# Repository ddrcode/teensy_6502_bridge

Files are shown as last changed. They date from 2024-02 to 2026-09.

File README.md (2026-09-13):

# W65C02-Serial port bridge for Teensy 4.1

This project is a simple bridge between the [W65C02 CPU](https://westerndesigncenter.com/wdc/documentation/w65c02s.pdf)
and a serial port, implemented for the [Teensy 4.1](https://www.pjrc.com/store/teensy41.html) development board.

The main purpose of this project is to provide cycle-by-cycle debugging capabilities for the W65C02, but it can serve
other purposes too, e.g.:

- __Comparative debugging for emulators__:
  You can run your 6502-family emulator in parallel with an actual CPU and compare the results
  in order to measure the accuracy of your emulator.
- __Emulated 8-bit computers with a physical processor__:
  You can implement an emulator of an 8-bit, 6502-based computer (e.g. the C64) that works
  (via this bridge) with a real CPU, while the other components of the system (like RAM, ROM,
  or the video chip) remain emulated
  (something like the [Neo 6502](https://www.olimex.com/Products/Retro-Computers/Neo6502/open-source-hardware)).

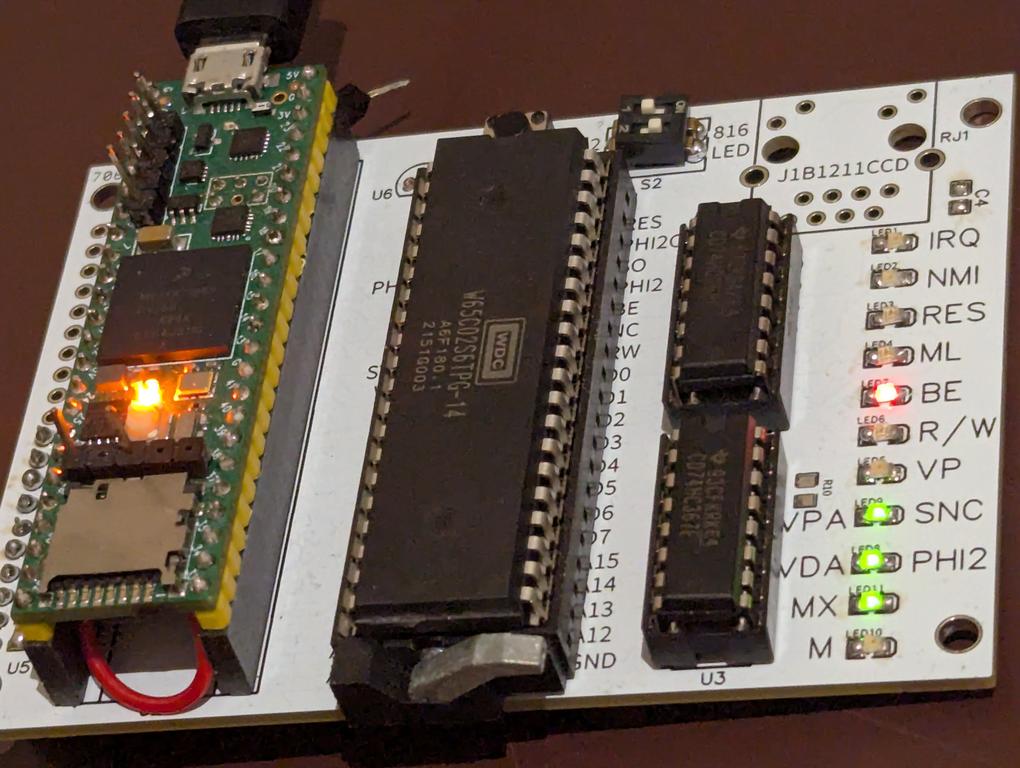
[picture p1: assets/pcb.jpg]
Example wiring


## Content of this repo

- C++ code for the Teensy 4.1 that enables full control over the W65C02 CPU via a serial port.
- An alternative [bare-metal Rust firmware](./firmware-rust/) with the same wire protocol
  (no Arduino toolchain required).
- [Examples](./examples/) (in C++ and Rust) demonstrating how to use the bridge from a program running on a
  computer.
- Host-side tooling plus unit/integration tests that exercise the serial protocol and pin-handling logic.
- An explanation of how to wire the Teensy to the W65C02 on a breadboard.
- Complete [PCB design and schematics](./pcb/) (with some extra features).
- [Documentation](./docs/): the [protocol specification](./docs/protocol.md), development guides for
  [C++](./docs/development-guide-cpp.md) and [Rust](./docs/development-guide-rust.md), a
  [macOS guide](./docs/macos.md), and the [project vision](./docs/vision.md) (the bridge and
  the machine - two modes of using the board).

## Wiring

The W65C02 CPU is a 40-pin chip with 37 signal pins (2 pins are for
power/ground and pin 35 is unused). As the Teensy board is equipped with more than 40 digital
input/output pins and allows for a serial connection via USB, it seems to be a perfect match for this
project. It is very simple to create this bridge on a breadboard.

Below is a pinout diagram of the W65C02 and the Teensy, as well
as the mapping between the CPU and Teensy pins.

```text
                                                        Teensy 4.1
                                                     +--------------+
                W65C02                           --- | GND      VIN | ---
            +------------+                   VP/ --- |  0       GND | ---
    VP/ <-- |  1      40 | <-- RES/              --- |  1      3.3V | ---
    RDY <-> |  2      39 | --> PHI2O       PHI1O --- |  2        23 | --- RES/
  PHI1O <-- |  3      38 | <-- SO/          IRQ/ --- |  3        22 | --- PHI2O
   IRQ/ --> |  4      37 | <-- PHI2          ML/ --- |  4        21 | --- RDY
    ML/ <-- |  5     @36 | <-- BE           NMI/ --- |  5        20 | --- SO/
   NMI/ --> |  6      35 | --- NC           SYNC --- |  6        19 | --- BE
   SYNC <-- |  7     *34 | --> RW/            A0 --- |  7        18 | --- M
    VDD --> |  8     *33 | <-> D0             A1 --- |  8        17 | --- RW/
     A0 <-- |  9*    *32 | <-> D1             A2 --- |  9        16 | --- D0
     A1 <-- | 10*    *31 | <-> D2                --- | 10        15 | --- D1
     A2 <-- | 11*    *30 | <-> D3             A3 --- | 11        14 | --- D2
     A3 <-- | 12*    *29 | <-> D4             A4 --- | 12        13 | --- PHI2
     A4 <-- | 13*    *28 | <-> D5            VDD --- | 3.3V     GND | --- GND
     A5 <-- | 14*    *27 | <-> D6             A5 --- | 24        41 | --- D3
     A6 <-- | 15*    *26 | <-> D7             A6 --- | 25        40 | --- D4
     A7 <-- | 16*    *25 | --> A15               --- | 26        39 | --- D5
     A8 <-- | 17*    *24 | --> A14               --- | 27        38 | --- D6
     A9 <-- | 18*    *23 | --> A13            A7 --- | 28        37 | --- D7
    A10 <-- | 19*    *22 | --> A12            A8 --- | 29        36 | --- A15
    A11 <-- | 20*     21 | --> GND            A9 --- | 30        35 | --- A14
            +------------+                   A10 --- | 31        34 | --- A13
                                             A11 --- | 32        33 | --- A12
    * - tri-state pin,                               +--------------+
    @ - async,
    / - active on low,
    M - routed to CPU pin 35 through the configuration switch (S2) on the PCB;
        unused with a W65C02, carries the E (emulation) status of a W65C816
```

### Default configuration

The table below (and the pinout above) illustrates the default configuration of the project.
To adjust the pin mapping, modify the `PINS_MAP` macro definition in the
[configuration file](./configuration.h).

The pin assignment is organized so that it leaves one SPI interface
available (pins 1, 10, 26 and 27), which can be used for an additional device (e.g. the [PCB](./pcb/)
gives the option to connect an ILI9341 screen). The firmware can drive that screen as an optional
live front panel (logic analyzer, address/data readouts, clock rate) - see the
[C++ development guide](./docs/development-guide-cpp.md#optional-ili9341-display).

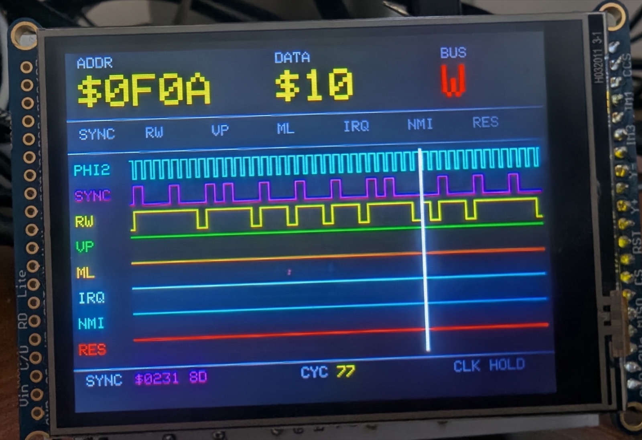
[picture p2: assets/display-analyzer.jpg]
Live front panel


| Teensy pin | CPU pin | CPU pin name | ←  → | CPU Pin name  | CPU pin | Teensy pin |
| --- | --- | --- | ---- | --- | --- | --- |
| 0 | 1 | Vector pull  | | Reset | 40 | 23 |
| 21 | 2 | Ready | | PHI2O | 39 | 22 |
| 2 | 3 | PHI1O | | Set overflow  | 38 | 20 |
| 3 | 4 | IRQ | | PHI2 | 37 | 13 |
| 4 | 5 | Memory lock  | | Bus enable | 36 | 19 |
| 5 | 6 | NMI | | NC / E (816)  | 35 | 18 (S2) |
| 6 | 7 | SYNC | | Read/Write | 34 | 17 |
| 3.3V | 8 | VDD | | D0 | 33 | 16 |
| 7 | 9 | A0 | | D1 | 32 | 15 |
| 8 | 10 | A1 | | D2 | 31 | 14 |
| 9 | 11 | A2 | | D3 | 30 | 41 |
| 11 | 12 | A3 | | D4 | 29 | 40 |
| 12 | 13 | A4 | | D5 | 28 | 39 |
| 24 | 14 | A5 | | D6 | 27 | 38 |
| 25 | 15 | A6 | | D7 | 26 | 37 |
| 28 | 16 | A7 | | A15 | 25 | 36 |
| 29 | 17 | A8 | | A14 | 24 | 35 |
| 30 | 18 | A9 | | A13 | 23 | 34 |
| 31 | 19 | A10 | | A12 | 22 | 33 |
| 32 | 20 | A11 | | Ground | 21 | GND |

### Minimal configuration

In the minimal configuration, the following CPU pins must be connected to the board:

- `A0-A15` - address bus (inputs)
- `D0-D7` - data bus (input or output)
- `RW` - read/write input; it indicates whether the data bus is in read (high) or write (low) state
- `PHI2` - clock signal input
- `GND` - ground, should be connected to a Teensy ground pin
- `VDD` - power; should be connected to the Teensy's 3.3V pin

In such a configuration the `RES`, `IRQ`, `NMI`, `BE` and `RDY` pins must also be connected to 3.3V,
ideally via a 1k resistor.

Please note that `RES` (pin 40) must be kept low for at least two cycles on power-on.
The bridge handles it programmatically, but if you intend not to connect the RES pin to the
Teensy, or want physical control over the reset state (e.g. in case of a power failure),
the best option is to drive the pin with a
[DS1818 Econo Reset](https://www.mouser.co.uk/datasheet/2/609/DS1818-3122611.pdf).

### Example

The photo shows the wiring on a solderable prototype board (a regular breadboard could be used instead).
All CPU pins are connected to the Teensy, apart from pin 35 (NC).
The CPU pin 8 (VDD) is connected via a [decoupling capacitor](https://en.wikipedia.org/wiki/Decoupling_capacitor).
Additionally, there are some LEDs indicating selected signals.

Example wiring

### Schematic and extended configuration

The schematic below illustrates the connectivity between the Teensy and the CPU, but also
provides some optional extras:

- a reset button
- indication LEDs
- SPI connectivity with an ILI9341 LCD.
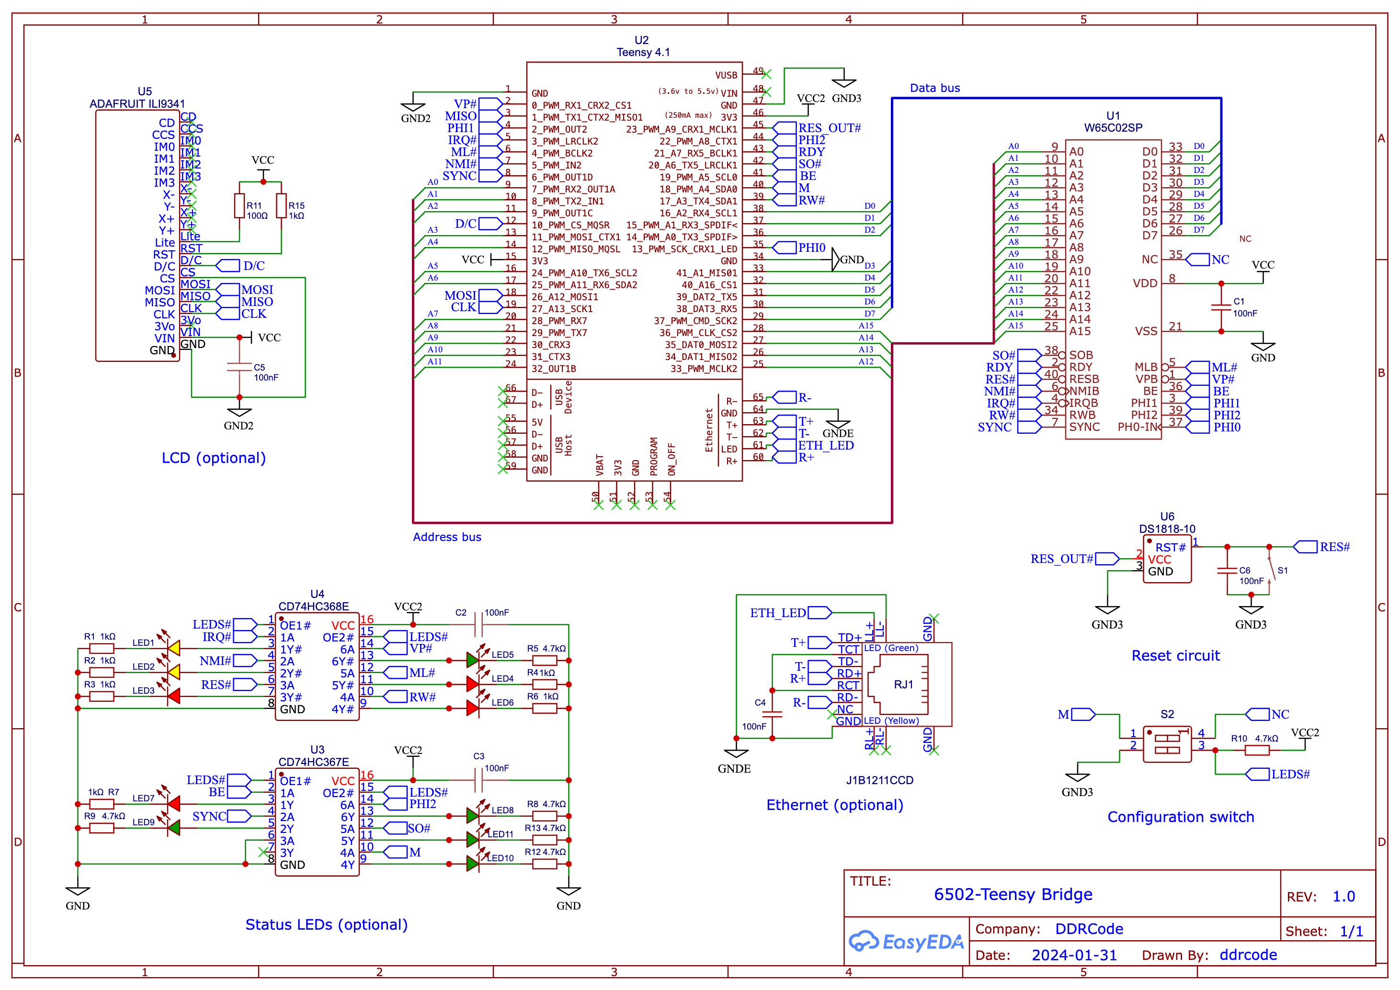
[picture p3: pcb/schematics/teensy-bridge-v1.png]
Schematic
  

### Warning

An incorrect connection may damage the CPU or the development board. Please pay extra attention to the
correctness of your wiring and double-check it before powering up your board.

## Compilation and execution

### With Arduino IDE and Teensyduino

1. Install the [Arduino IDE](https://www.arduino.cc/en/software)
1. Install and configure [Teensyduino](https://www.pjrc.com/teensy/teensyduino.html)
1. Clone this project into your Arduino sketches folder (usually `~/Arduino/sketches`)
1. Click menu `Sketch / Compile` to compile
1. Click menu `Sketch / Upload` to upload to the Teensy board

### With Arduino CLI

Follow [this
post](https://forum.pjrc.com/index.php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)
to see how to configure the Arduino CLI for Teensy, or do these steps (the third one is for Linux only):

```
arduino-cli config add board_manager.additional_urls https://www.pjrc.com/teensy/package_teensy_index.json
arduino-cli core install teensy:avr
wget https://www.pjrc.com/teensy/00-teensy.rules -P /etc/udev/rules.d
```

- to compile: `make build`
- to upload: `make upload`

`make upload` uses `teensy-loader-cli`, so the Teensy Loader application must be available on your PATH.

On macOS `make upload` may fail with `Device is in use by "dummy" driver`, and the serial
ports are named differently — see [Running the bridge on macOS](./docs/macos.md) for
working upload options and other Darwin-specific details.

### Running the host-side runners

After flashing the firmware you can exercise the bridge directly from your workstation. Both host examples
share the same CLI flags; at minimum you must provide the serial `--port` and the path to a 6502 binary via
`--program`. When you invoke the Makefile targets, the `PROGRAM` variable defaults to `examples/test.p`, and you
can point it somewhere else as needed.

The Makefile exposes convenience targets that forward those flags for you:

```bash
PORT=/dev/ttyACM0 make run-cpp   # builds and runs the C++ host runner
PORT=/dev/ttyACM0 make run-rust  # builds and runs the Rust host runner (cargo)
PROGRAM=examples/other.bin PORT=/dev/ttyACM0 make run-cpp
```

Pass `--halfcycles` to either executable if you want to log both halves of the clock and show the PHI pins in the
log output. Pass `--step` to execute cycle by cycle: the runner pauses after every cycle with the CPU frozen
(ideal for watching the indication LEDs) and advances on Enter - see the
[examples Readme](./examples/README.md) for the full list of step commands. Run `arduino-cli board list` whenever you need to confirm which `/dev/tty*` entry corresponds to the
Teensy (on macOS the port appears as `/dev/cu.usbmodem*` — see [docs/macos.md](./docs/macos.md)).

##### Install Arduino CLI and dependencies with Nix and Direnv

If you are not using Nix packages, then you don't know how much you are missing in terms of convenience and reproducible dev environments - [start](https://nixos.org/download) today :-)

1. Clone the repo and cd into the project's directory
1. If you use [Direnv](https://direnv.net/), just execute `direnv allow`; otherwise type `nix-shell`
1. Wait until all the dependencies download and configure
1. You can now use `make build` and `make upload`
1. I've added [`treefmt`](https://github.com/numtide/treefmt) to the dependencies, so you can format the
   code after changes by executing `treefmt`

## Example

There is a complete example program in the [examples folder](./examples) that demonstrates
how to execute a 6502 binary with the bridge and RAM emulated on the host machine
(not on the Teensy). See the [Readme file](./examples/README.md) for details.

## Data structure and message protocol

The host and the bridge exchange short, framed messages over the serial port: a type byte, a
payload and a checksum. In normal operation both sides exchange 7-byte _pins messages_ carrying
the state of all 40 CPU pins (one per bit) - one request-response pair per clock half-cycle, with
the host driving `PHI2` and emulating the memory. The bridge validates every incoming message and
responds with a short error message when it rejects one.

The complete specification - the message framing, the exact bit layout of the pins payload, the
messaging order and the timing characteristics - lives in [docs/protocol.md](./docs/protocol.md).

## Working with other CPUs from the 6502 family

This project is meant to work specifically with the W65C02 CPU. The main reason
is that the W65C02 is static, which means it can easily be cycled step by step at any speed -
very useful for debugging. Some other CPUs, like the C64's MOS6510, have
a minimum clock speed limitation (~100 kHz).

The project should work fine with other CPUs from the WDC family, especially with the
65C802, due to pin layout compatibility. Although untested, the 65C802 should work
as-is, without any changes to the current code.

There is a plan to make the project fully compatible with the W65C816, however that
requires some changes in the handling of the 24-bit address bus (there is already a
[ticket](https://github.com/ddrcode/teensy_6502_bridge/issues/3) for that).

This bridge may still work with some other CPUs from the 6502 family, but some adjustments
may be required, as those processors may have different pin layouts. Also,
a minimum clock speed requirement may be a blocker, due to the limited speed of the bridge itself
(see the section below). And finally - the WDC family processors work perfectly at 3V, which matches
the Teensy 4.1 pin voltage. Other processors, like the original 6502/6510, may be 5V-only.
That would require further modifications.

## Speed limitations

The speed of the bridge is limited by the speed of the serial port. The bridge sends 40 bits of data
in both directions for every single half-cycle (clock phase). To obtain a CPU speed of
1 MHz, the serial port would have to operate at 160 Mbit/s. Although the Teensy 4.1 is equipped
with a high-speed USB 2.0 port, which - in theory - allows for 480 Mbit/s, in reality the serial port
emulation uses a single USB channel only and there is an overhead related
to the creation of USB packets. The current speed I've achieved in my tests is around
0.5 Mbit/s. This is quite sufficient for any form of debugging and execution of test programs,
but definitely too slow for running any real-time applications.
For example, starting the C64 Kernal via the bridge takes around 300 seconds.

I've created a [ticket](https://github.com/ddrcode/teensy_6502_bridge/issues/8) for this issue.
Contributors are welcome!

## References

- [W65C02 datasheet](https://westerndesigncenter.com/wdc/documentation/w65c02s.pdf)
- [Teensy 4.1](https://www.pjrc.com/store/teensy41.html)
- [6502 Primer: What do I do with the "mystery" pins](https://wilsonminesco.com/6502primer/MysteryPins.html)

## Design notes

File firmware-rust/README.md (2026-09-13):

# W65C02-Teensy Bridge - Rust firmware

A bare-metal Rust implementation of the bridge firmware, functionally equivalent
to the C++ firmware in the repository root: the same
[serial protocol](../docs/protocol.md) (framed messages, checksum validation,
error replies), the same data-bus gating (driven only during the high clock
phase of read cycles), and the same high-speed USB. The host runners and test
programs work with either firmware unchanged.

Built on [teensy4-rs](https://github.com/mciantyre/teensy4-rs) (`teensy4-bsp`),
with USB CDC via `imxrt-usbd` + `usbd-serial`. No Arduino, no arduino-cli.

## Extras over the C++ firmware

- **Self-rebooting flash**: opening the serial port at **134 baud** reboots the
  board into the HalfKay bootloader (the same convention Teensyduino uses), so
  reflashing needs no button press:

  ```bash
  stty -f /dev/cu.usbmodemXXXX 134    # macOS (use /bin/stty if GNU coreutils shadows it)
  stty -F /dev/ttyACM0 134            # Linux
  ```

- The device enumerates as `W65C02 Bridge (Rust)` (serial `6502-RS-2`), so it is
  easy to tell which firmware is flashed.

## Building and flashing

```bash
cd firmware-rust
make build    # cargo build --release (rustup installs the target automatically)
make hex      # ELF -> teensy-6502-bridge.hex (llvm-objcopy from the toolchain)
make flash    # flash with teensy-loader-cli (see below)
make test     # host-side unit tests of the protocol/payload logic
```

`make flash` expects a native `teensy-loader-cli` on the PATH (on macOS build it
from source - see [docs/macos.md](../docs/macos.md); the nixpkgs build does not
work there). If the Rust firmware is already running, trigger the 134-baud
reboot first (or let `teensy-loader-cli -w` wait and press the button).

## Source layout

| File | Responsibility |
| ---- | --- |
| `src/main.rs` | Board/GPIO/USB setup and the request-response loop |
| `src/protocol.rs` | Message framing: sizes, checksums, error replies, byte-stream accumulator (host-tested) |
| `src/payload.rs`  | The 40-bit pin payload bit layout (host-tested, incl. a real hardware-captured vector) |
| `src/lib.rs` | `no_std` on target, `std` for host tests |

## Hardware notes (learned the hard way)

- Pin mapping comes from the `teensy4-pins` pad table - every pin is created
  through the HAL's type-checked API, so a wrong pin/port pairing fails at
  build/boot rather than silently writing to the wrong register.
- All output pads are configured with **SION** (Software Input On), so the
  driven levels can be read back through PSR. Without it, `handle_cycle`'s
  `RW && PHI2` bus gate reads PHI2 as always-low and the data bus is never
  driven - the CPU then executes garbage from a floating bus.
- Data-bus direction is flipped by re-running the HAL's documented-reentrant
  `Output::without_pin`/`Input::without_pin` constructors (a single GDIR
  register write per line).

## Limitations vs the C++ firmware

- No debug/diagnostics modes and no ILI9341 display support (the display could
  be added later with `embedded-graphics` + an `ili9341` driver crate).
- Async (embassy) is not used: `embassy-imxrt` targets the i.MX RT600 family,
  not the Teensy's RT1062. A polling loop is the right shape for this
  latency-bound protocol anyway; RTIC would be the natural framework if
  interrupt-driven structure is ever needed.

## Verification

The firmware passes the same hardware test battery as the C++ one: protocol
probe (checksum/type error replies, valid pins exchange), deterministic
cycle-exact soak runs, and the `examples/test.p` correctness check - at the
same throughput (~5,000 CPU cycles/s over high-speed USB).

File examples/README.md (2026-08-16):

# Example - program runner

This folder hosts the workstation-side programs (C++ and Rust) that toggle `PHI2`, emulate RAM, and exchange
pin states with the Teensy bridge over USB. Both implementations behave identically; choose the toolchain you
prefer.

## Requirements

- Teensy 4.1 running the bridge firmware from this repository
- A W65C02 wired to the Teensy (at minimum: address bus, data bus, `PHI2`, and `RW/`)
- A serial port path such as `/dev/ttyACM0`
- A 6502 binary (the demo uses `examples/test.p`)

## Quick start

Use the Makefile helpers to build and run either example with one command:

```bash
PORT=/dev/ttyACM0 make run-cpp
PORT=/dev/ttyACM0 make run-rust
PROGRAM=examples/custom.bin PORT=/dev/ttyACM0 make run-cpp
```

`PORT` selects the serial device while `PROGRAM` decides which binary is loaded into the emulated RAM. Append
`--halfcycles` to either command when you want to observe both halves of every cycle and include the `PHI1O/PHI2O`
signals in the log.

Append `--step` to execute the program cycle by cycle: the runner pauses after every logged cycle
(with the CPU frozen and its pins holding the printed state - ideal for watching the indication
LEDs), and waits for a command: `Enter` advances one cycle, a number runs that many cycles,
`c` switches back to free-running and `q` quits. Combined with `--halfcycles` it steps through
individual half-cycles.

## Manual compilation

If you prefer to compile by hand, follow the steps below.

### C++ version

1. Discover the Teensy port: `arduino-cli board list`
2. Build: `g++ -std=c++17 -O2 -o example.out *.cpp`
3. Run: `./example.out --port /dev/ttyACM0 --program ../test.p [--halfcycles]`

### Rust version

1. Discover the Teensy port: `arduino-cli board list`
2. Build: `cargo build`
3. Run: `cargo run -- --port /dev/ttyACM0 --program ../test.p [--halfcycles]`

## Expected result

If everything is connected correctly, the program should produce
output like the one shown below. It executes a tiny program that adds two
16-bit numbers together (see the [source](./test.asm)). Each line contains
all the relevant fields, so you can scroll freely without losing the column headers.

```text
Cycle=000009 Half=H Addr=$FFFC Data=$00 RW=R SYNC=0 VP=0 IRQ=1 NMI=1 RES=1
Cycle=000010 Half=H Addr=$FFFD Data=$02 RW=R SYNC=0 VP=0 IRQ=1 NMI=1 RES=1
Cycle=000011 Half=H Addr=$0200 Data=$A9 RW=R SYNC=1 VP=1 IRQ=1 NMI=1 RES=1
Cycle=000012 Half=H Addr=$0201 Data=$03 RW=R SYNC=0 VP=1 IRQ=1 NMI=1 RES=1
Cycle=000013 Half=H Addr=$0202 Data=$8D RW=R SYNC=1 VP=1 IRQ=1 NMI=1 RES=1
Cycle=000014 Half=H Addr=$0203 Data=$FF RW=R SYNC=0 VP=1 IRQ=1 NMI=1 RES=1
Cycle=000015 Half=H Addr=$0204 Data=$FF RW=R SYNC=0 VP=1 IRQ=1 NMI=1 RES=1
Cycle=000016 Half=H Addr=$FFFF Data=$03 RW=W SYNC=0 VP=1 IRQ=1 NMI=1 RES=1
```

The first few logged cycles may differ from run to run - they show the CPU's internal reset
sequence (dummy fetches and three stack accesses) before the reset vector is fetched from
`$FFFC`/`$FFFD`, with the vector pull clearly visible as `VP=0`. From that point on the trace
is fully deterministic.

Running the tools with `--halfcycles` prints both halves of every cycle and appends
`PHI1O`/`PHI2O` at the end of each line for deeper timing inspection.

## How does the example work?

1. The runner loads the binary at $0200, seeds the reset/IRQ/NMI vectors, and asserts reset low for two full cycles.
2. Each half-cycle writes a 40-bit pin snapshot to the bridge, toggling `PHI2` in the payload. The low phase captures
	the address and `RW/` state; the high phase either supplies memory data (reads) or stores results (writes).
3. Every completed bus operation is logged as labeled key/value pairs, so you can follow execution without a logic
	analyzer.

For more details see the development guides for [C++](../docs/development-guide-cpp.md) and
[Rust](../docs/development-guide-rust.md), and the [protocol specification](../docs/protocol.md).

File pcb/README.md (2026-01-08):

# PCB

This folder contains everything you need to fab the optional Teensy↔W65C02 carrier board: schematics, rendered
views, manufacturing files, and a bill of materials.

## Folder contents

- `schematics/` – source diagram plus a printable PNG
- `gerber/` – ready-to-send fabrication outputs (ZIP all files and upload to your PCB house)
- `assets/` – 3D/top/bottom previews for quick reference

## Schematics

schematics

## PCB Design

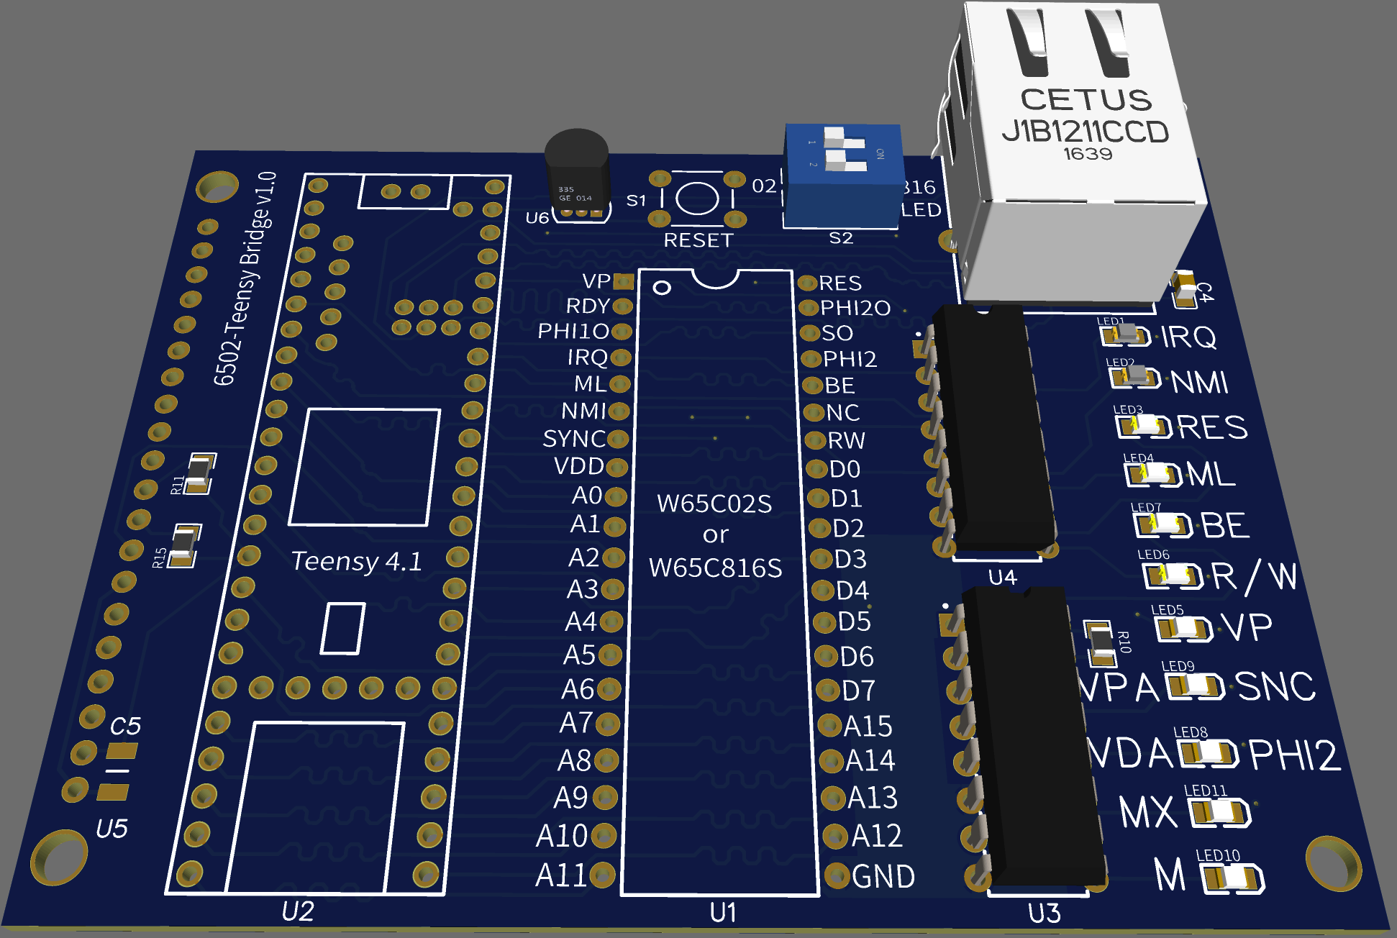
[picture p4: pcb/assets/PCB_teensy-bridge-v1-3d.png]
3d view


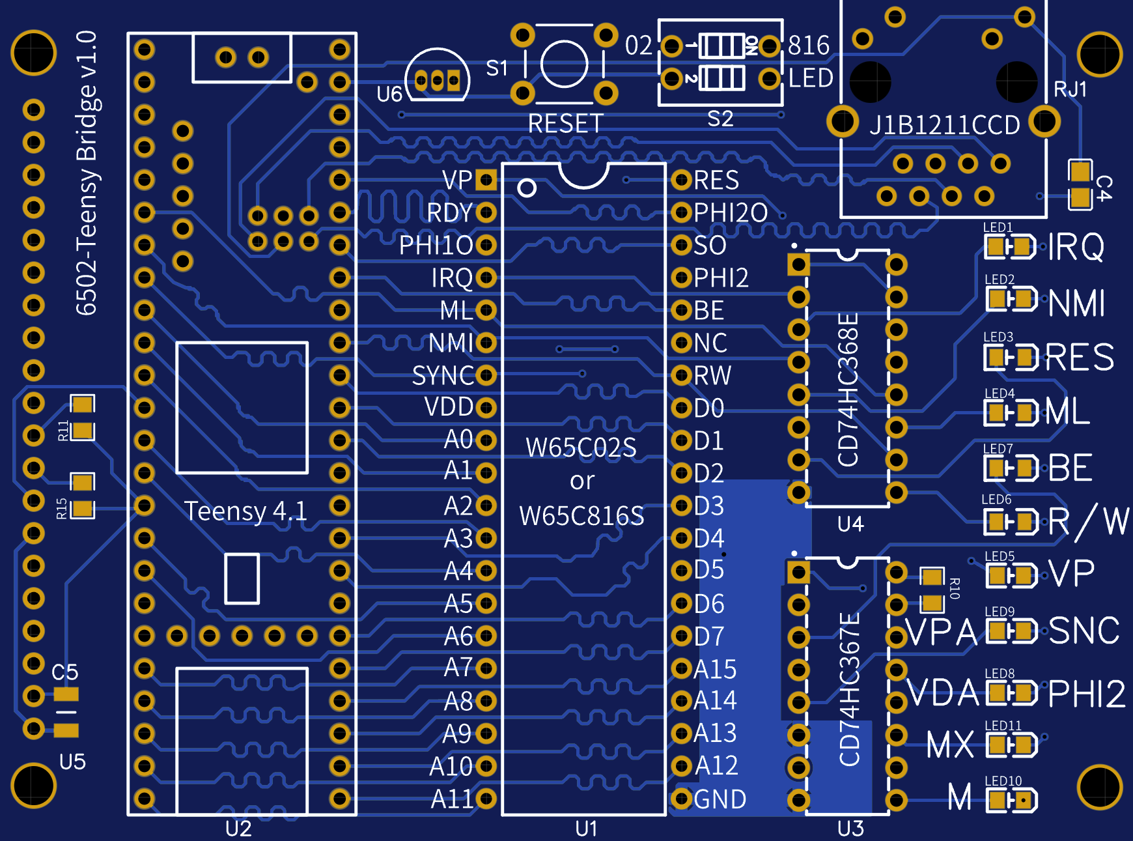
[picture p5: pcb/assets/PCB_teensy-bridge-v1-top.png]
Top view


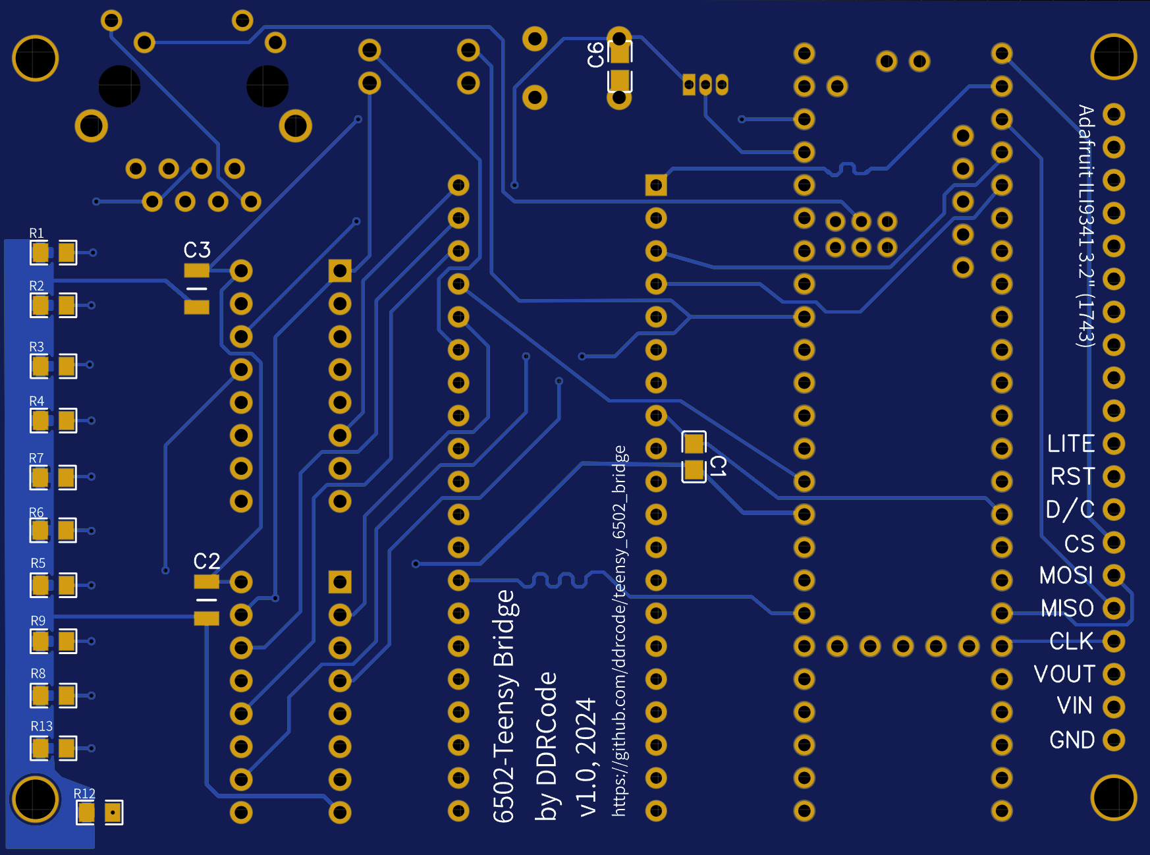
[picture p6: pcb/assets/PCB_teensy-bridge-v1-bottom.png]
Bottom view


## BOM

Populate only the components you care about: the mandatory list yields a minimal functional bridge, while the
optional sections add Ethernet, LED diagnostics, or an SPI display header.

### Mandatory components

| Ref | Component | Qty | Size | Description |
| --- | --- | --- | --- | --- |
| U1  | W65C02 or W65C816 | 1 | PDIP-40  | CPU |
| U2  | Teensy 4.1 | 1 | | Microcontroller dev board |
| U6  | [DS1818-10](https://www.mouser.co.uk/datasheet/2/609/DS1818-3122611.pdf) | 1 | TO-92-3  | EconoReset with push button |
| C1  | 100nF | 1 | 0805 SMD | Unpolarized capacitor |
| S1  | TL1105 | 1 | 4 pin | Tactile switch |
| S2  | ADE | 1 | DIP-2 | 2-pos DIP switch |

### Optional components

#### Ethernet

| Ref | Component  | Qty | Size | Description |
| --- | --- | --- | --- | --- |
| RJ1 | J1B1211CCD | 1 | | RJ45 Socket |
| C4  | 100nF | 1 | 0805 SMD | Unpolarized capacitor |

#### Debugging LEDs

| Ref | Component | Qty | Size | Description |
| --- | --- | --- | --- | --- |
| U3 | [CD74HC367E](https://www.ti.com/lit/ds/symlink/cd54hc368.pdf?ts=1706075936400) | 1 | PDIP-16  | Line driver |
| U4 | [CD74HC368E](https://www.ti.com/lit/ds/symlink/cd54hc368.pdf?ts=1706075936400) | 1 | PDIP-16  | Inverting line driver |
| C2,C3 | 100nF | 2 | 0805 SMD | Unpolarized capacitor |
| LED5, LED8-11  | Standard LED - SMD | 5 | 0805 SMD | Green LEDs |
| R5, R8-R11 | 4.7k Ohm | 5 | 0805 SMD | Resistors for green LEDs  |
| LED3-4, LED6-7 | Standard LED - SMD | 4 | 0805 SMD | Red LEDs |
| R3-R4, R6-R7 | 3k Ohm | 4 | 0805 SMD | Resistors for red LEDs |
| LED1, LED2 | Standard LED - SMD | 2 | 0805 SMD | Yellow LEDs |
| R1, R2 | 4.7k Ohm | 2 | 0805 SMD | Resistors for yellow LEDs |

#### SPI Screen

| Ref | Component | Qty | Size | Description |
| --- | --- | --- | --- | --- |
| U5  | [ADAFRUIT ILI9341](https://www.adafruit.com/product/1743) | 1 | PDIP-16  | 3.2", 320x200px SPI screen |
| C5  | 100nF | 1 | 0805 SMD | Unpolarized capacitor |
| R11 | 100 Ohm | 1 | 0805 SMD | Screen light resistor |
| R15 | 1k Ohm | 1 | 0805 SMD | Screen reset resistor |

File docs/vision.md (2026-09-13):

# Vision: one board, two modes

This project began as - and its name still says - a *bridge*: a Teensy 4.1 that hands full
control of a physical W65C02 to software running on a host computer. That mode is mature,
tested and in daily use. But the board that grew around the bridge - a 600 MHz
microcontroller, a real CPU, a screen, an Ethernet jack - turned out to be provisioned for
something more. This document names the two ways the board can be used, shows that they are
one architecture rather than two projects, and sketches where that leads.

## Mode 1 - the bridge (what exists)

```
 host machine  ── USB serial ──>  Teensy  ── 40 pins ──>  W65C02
 emulated world                   transparent             real CPU
 + the clock                      servant
```

The host owns everything: it drives the clock one half-cycle per message, emulates the
memory and peripherals, and sees the state of all 40 CPU pins in every reply (see the
[protocol specification](./protocol.md)). The CPU runs at a few kHz - limited by USB
round-trip latency - which is not a flaw but the point: every cycle is observable,
steppable and bit-for-bit reproducible.

This is the project's laboratory identity: cycle-by-cycle debugging, lockstep validation of
cycle-accurate emulators, and silicon-in-the-loop test suites. Everything in this repository
serves Mode 1 today.

## Mode 2 - the machine (what could exist)

```
                Teensy  ── 40 pins ──>  W65C02
                emulated world           real CPU
                + the clock
                + screen, keyboard,
                  storage, network
```

No serial connection and no host: the Teensy *is* the computer. It free-runs the clock,
serves the address space from its own RAM, maps ROM images from flash, and emulates the
peripherals - with the real 6502 as the one component that isn't emulated. The concept is
proven by the [Neo6502](https://www.olimex.com/Products/Retro-Computers/Neo6502/open-source-hardware) -
which the main README has cited as an inspiration since 2023. Mode 2 was always purpose #2
in the README; it just never had firmware.

The board is better prepared for this than its name suggests:

| Resource | Mode 2 role |
| --- | --- |
| 600 MHz Cortex-M7 | ~600 microcontroller cycles per CPU cycle at a 1 MHz bus - room for memory *and* device emulation; 1-3 MHz looks feasible bit-banged (the RP2040-based Neo6502 reaches ~6 MHz with PIO assist) |
| 512 KB tightly-coupled RAM | The entire 64 KB address space with single-cycle access, several times over |
| 8 MB flash | ROM images (a C64 kernal is 8 KB; this fits a thousand of them) |
| PSRAM pads (up to 16 MB) | RAM expansions - an emulated REU, banked memory for the '816 |
| ILI9341 320×240 | The C64's 320×200 display fits **pixel-perfect**, with a 40-pixel status strip to spare |
| Ethernet (PCB provision) | File transfer, remote disks, network-era retro experiments |
| USB host (Teensy pads, unrouted on PCB v1.0) | A real keyboard - the missing piece; a v1.1 header candidate (#15) |

## Not two projects: the probe and the target

The unifying observation: **Mode 1 is the built-in debug probe of Mode 2's computer.** That
is the architecture of every modern dev board - a target plus an on-board debugger - except
here the target is a 1975 CPU and the probe speaks cycle-exact truth.

Concretely, one firmware with two loops over the shared pin layer:

- **Standalone**: boot into machine mode; the world runs at speed.
- **Attach**: a host opens the serial port (DTR) - the machine freezes mid-cycle (the W65C02
  is fully static, so "freeze" is literal and lossless) and the bridge protocol takes over.
  The host now steps *the actual running computer*, with its live memory image, on the
  front panel and in the trace.
- **Detach**: DTR drops; the machine resumes as if nothing happened.

Under this reading the project's name survives: the board bridges a real CPU to an emulated
world - Mode 1 keeps that world on the host, Mode 2 moves it onto the Teensy. Which side of
the USB cable the world lives on was never part of the name.

## What the reframe explains

Several design questions that looked like bugs are really *mode mismatches*:

- **The reset button** (#22): reset is clock-synchronous, so a button is meaningless while
  the clock is host-driven and idle (Mode 1) - but works exactly as intended against a
  free-running clock (Mode 2). The v1.0 DS1818 circuit, including its 150 ms debounce
  stretch, was a perfectly reasonable *Mode 2* reset circuit installed in a Mode 1 project.
- **The NMI button** (#15): same story - natural in Mode 2, where presses occur against a
  ticking application.
- The proposed button circuits (pull-up + button + Teensy open-drain, firmware observing
  the net) are deliberately **mode-agnostic**: in Mode 2 the buttons work electrically the
  classic way *and* the firmware sees them - which matters, because a reset that restarts
  the CPU without resetting the emulated chipset would desynchronize the machine. In Mode 1
  the same wiring lets the firmware escort a button press with clock cycles.

## Direction, not commitment

Mode 1 remains the core of this repository and stays stable - it is the identity the test
suites, the sibling projects and the documentation depend on. Mode 2 is an unexplored
direction with an honest sequencing already visible:

1. **W65C816 support** (#3) - firmware pin modes, the groundwork for bigger machines.
2. **A machine-mode prototype** - free-running clock + RAM/ROM from the Teensy, no devices:
   the memory-on-Teensy experiment, which doubles as the bridge's own speed unlock.
3. **Devices** - the ILI9341 as a memory-mapped display, keyboard via a USB-host header
   (v1.1), storage and network later.
4. **The attach/detach probe** - the moment the two modes become one instrument.

None of this is promised. But a board with a real 6502, a screen and a network jack should
not have to pretend it is only a cable.

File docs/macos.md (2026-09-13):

# Running the bridge on macOS

The project was developed on Linux, but everything works on macOS too — the serial
ports just have different names, and uploading the firmware needs a different tool.
This page collects everything Darwin-specific.

## Finding the serial port

When the Teensy runs the bridge firmware, it appears as `/dev/cu.usbmodemXXXXXXXXX`
(instead of Linux's `/dev/ttyACM0`):

```bash
ls /dev/cu.usbmodem*
# or
make detect-port          # wraps `arduino-cli board list`
```

Two things to know:

- Use the `/dev/cu.*` device, not its `/dev/tty.*` twin. On macOS the `tty.*`
  variant blocks on open until a carrier signal appears; `cu.*` (the "call-out"
  device) opens immediately, which is what the host runners expect.
- The number in the device name identifies the physical USB port, so it changes
  when you plug the board into a different socket.

Once you know the port:

```bash
PORT=/dev/cu.usbmodemXXXXXXXXX make run-rust    # or run-cpp
```

## Cables and hubs

Prefer connecting the Teensy directly to the computer. Some USB hubs (and all
charge-only cables) prevent the board from enumerating at all — if the board is
invisible in `ioreg -p IOUSB` even in bootloader mode (button pressed), suspect
the path to the machine before suspecting the firmware.

## Uploading the firmware

### Why `make upload` may fail

`make upload` calls `teensy-loader-cli`. If yours comes from nixpkgs (as with this
project's `shell.nix`) or is any other build compiled against libusb, it fails on
macOS like this:

```text
Waiting for Teensy device...
Device is in use by "dummy" driver
Unable to claim interface, check USB permissions
```

Despite the hint, this is not a permission problem (macOS has no udev equivalent,
and doesn't need one). The Teensy bootloader is a USB HID device, which macOS's
own HID driver claims automatically. The libusb code path then tries the Linux
trick of detaching the kernel driver — an operation that doesn't exist on macOS —
and gives up. (The name "dummy" is a placeholder returned by libusb-compat, which
cannot even query the real driver's name on Darwin.) Loaders built with Apple's
native IOKit HID API coexist with the Apple driver and work without any tricks;
that's what both options below use.

### Option 1 — PJRC tools from the Teensy Arduino core

If you installed the `teensy:avr` core for `arduino-cli` (see the main README),
the native tools are already on your disk:

```bash
TOOLS=$(ls -d ~/Library/Arduino15/packages/teensy/tools/teensy-tools/* | sort -V | tail -1)

make build
open -g "$TOOLS/teensy.app"     # start Teensy Loader in the background
"$TOOLS/teensy_post_compile" -file=teensy_6502_bridge.ino -path="$PWD/target" \
    -tools="$TOOLS" -board=TEENSY41 -reboot
```

Press the button on the board if the loader waits for it. On Apple Silicon these
tools are x86_64 binaries, so Rosetta 2 must be installed
(`softwareupdate --install-rosetta`).

### Option 2 — build `teensy_loader_cli` natively

The upstream `teensy_loader_cli` works fine on macOS when compiled with its
IOKit backend (a 30-second build):

```bash
git clone https://github.com/PaulStoffregen/teensy_loader_cli
cd teensy_loader_cli
make OS=MACOSX      # inside this project's nix-shell add: CC=/usr/bin/clang
```

Then, from the project directory:

```bash
make build
path/to/teensy_loader_cli --mcu=TEENSY41 -w -v target/teensy_6502_bridge.ino.hex
```

Note: the repository Makefiles invoke the tool as `teensy-loader-cli` (the nixpkgs spelling) -
rename or symlink your natively built binary accordingly if you want `make upload` and
`make flash` to use it.

The GUI [Teensy Loader](https://www.pjrc.com/teensy/loader_mac.html) from PJRC is
a third alternative if you prefer clicking.

## Recognizing the bootloader

Pressing the button puts the board into the HalfKay bootloader. Two things
surprise people:

- The bootloader is **not** a serial port — `/dev/cu.usbmodem*` disappears while
  the board sits in bootloader mode. That's normal; the port comes back once new
  firmware is flashed and the board reboots.
- The bootloader publishes no product-name string, so it's easy to miss in USB
  listings. Look for the PJRC vendor/product IDs instead:

```bash
ioreg -p IOUSB -w0 -l | grep -E 'idVendor" = 5824|idProduct" = 1144'
# 5824 = 0x16C0 (PJRC), 1144 = 0x0478 (HalfKay bootloader)
```

If those IDs show up, the board and the cable are fine — everything is ready for
flashing.

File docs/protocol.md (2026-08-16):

# Bridge message protocol

This document specifies the serial protocol spoken between a host computer and the Teensy bridge.
If you want to implement your own host-side client, this page is all you need; reference
implementations in C++ and Rust live in the [examples folder](../examples/).

## Message envelope

The host and the bridge exchange short, framed messages. Every message has the same envelope:

| Offset | Size | Field | Description |
| --- | ---- | --- | --- |
| 0 | 1 | Message type | See the table below |
| 1 | N | Payload | Size depends on the message type |
| N+1 | 1 | Checksum | Sum of all preceding bytes (type + payload), wrapping around 8 bits  |

## Message types

| Type | Name | Payload size | Total size | Description |
| ---- | --- | --- | --- | --- |
| 0 | Error  | 1 | 3 | Error code - sent by the bridge when it rejects a message |
| 1 | Status | 1 | 3 | Reserved for future use |
| 2 | Pins | 5 | 7 | State of all 40 CPU pins - the only type the host may send |

In normal operation the communication consists of pins messages (type 2) flowing in both directions:
the host sends the desired state of the pins it controls, the bridge applies it, lets the CPU react,
samples all 40 pins and responds with a single pins message containing the result.

## Validation and errors

The bridge validates every incoming message. When the message type is not a pins message, or the
checksum doesn't match, the bridge leaves the CPU pins untouched and responds with a 3-byte error
message instead of a pins message. Host implementations should therefore read the type byte of a
response first, and only then the rest of it (both example runners do), and should verify the
checksum of every pins response.

| Error code | Meaning |
| --- | --- |
| 1 | Invalid message type - the bridge accepts pins messages (2) only |
| 2 | Checksum mismatch |

## Pins payload

The payload of a pins message contains the status of all 40 CPU pins (one per bit).
Imagine the CPU pins as a 40-bit number, with pin 1 representing the least significant bit (bit 0)
and pin 40 the most significant bit. That number is transferred in
[big-endian](https://en.wikipedia.org/wiki/Endianness) format, so payload byte 0 (message byte 1)
contains the status of pins 40 to 33 (reading bits left to right), etc.
The table below illustrates the exact structure of the payload.

| Payload byte | Bit 7 | Bit 6 | Bit 5 | Bit 4 | Bit 3 | Bit 2 | Bit 1 | Bit 0 |
| --- | --- | --- | --- | --- | --- | --- | --- | --- |
| 0 | Pin 40<br>`RES/` | Pin 39<br>`PHI2O` | Pin 38<br>`SO/`  | Pin 37<br>`PHI2` | Pin 36<br>`BE` | Pin 35<br>`NC` | Pin 34<br>`RW/` | Pin 33<br>`D0`  |
| 1 | Pin 32<br>`D1` | Pin 31<br>`D2` | Pin 30<br>`D3` | Pin 29<br>`D4` | Pin 28<br>`D5` | Pin 27<br>`D6` | Pin 26<br>`D7`  | Pin 25<br>`A15` |
| 2 | Pin 24<br>`A14`  | Pin 23<br>`A13` | Pin 22<br>`A12`  | Pin 21<br>`VSS`  | Pin 20<br>`A11`  | Pin 19<br>`A10`  | Pin 18<br>`A9`  | Pin 17<br>`A8`  |
| 3 | Pin 16<br>`A7` | Pin 15<br>`A6` | Pin 14<br>`A5` | Pin 13<br>`A4` | Pin 12<br>`A3` | Pin 11<br>`A2` | Pin 10<br>`A1`  | Pin  9<br>`A0`  |
| 4 | Pin  8<br>`VDD`  | Pin  7<br>`SYNC`  | Pin  6<br>`NMI/` | Pin  5<br>`ML/`  | Pin  4<br>`IRQ/` | Pin 3<br>`PHI1O` | Pin  2<br>`RDY` | Pin  1<br>`VP/` |

## Messaging order

As the Teensy bridge doesn't implement a clock, the communication must start on the host side - the
host is responsible for sending the `PHI2` values (pin 37), and - to make the CPU _tick_ - the value
must be inverted in every pins message sent by the host.

Every write to the bridge must be followed by a read, even if you are not planning to use the data
from the bridge (a typical request-response approach). In other words: every single half-cycle
(clock phase) consists of a write to the serial port followed by a read. A full CPU cycle consists
of write-read-write-read operations, with pin 37 set to 0 the first time and to 1 the second time.

During the first half-cycle the CPU executes internal operations, resulting in setting the address
bus and the `RW/` pin. The second half-cycle is a _memory cycle_, when the CPU reads or writes its
data pins. The algorithm below demonstrates the typical interaction with the CPU, respecting both
clock phases.

1. First half-cycle
   1. Set `PHI2` pin to LOW (0) in the payload
   1. Send a pins message to the serial port
   1. Read the 7-byte response from the serial port
   1. Extract the address and the read/write state (pin 34) from the response payload
1. Second half-cycle
   1. Set `PHI2` pin to HIGH (1) in the payload
   1. In case of a read operation (pin 34 is high) - read the value from the memory and set the data pins
   1. Send a pins message to the serial port
   1. Read the 7-byte response from the serial port
   1. In case of a write operation (pin 34 was low in the first half-cycle) - read the value from the data pins and store it in the memory

Note that the bridge drives the CPU data pins only during the high clock phase of read cycles -
like a real memory's output enable gated with `RW/` and `PHI2`. For the entire low phase (and for
write cycles) the data bus is released, so the bus turnaround gap between transactions is
physically real and observable on the bench.

## Timing

No pacing is required on the host side: the bridge replies only after the half-cycle has been fully
handled, so the response itself is the synchronization point, and the host can send the next message
immediately after reading it. The W65C02 is a fully static design, so arbitrarily long gaps between
messages are fine as well - the CPU simply holds its state. In practice the throughput is limited by
the serial round-trip time (around 100 µs per half-cycle over USB), which caps the effective CPU
clock at roughly 5 kHz.

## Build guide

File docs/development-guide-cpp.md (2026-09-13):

# C++ development guide

This guide covers the two C++ parts of the project: the Teensy firmware (the bridge itself) and
the C++ host runner in [examples/cpp](../examples/cpp/). For the wire format between them, see the
[protocol specification](./protocol.md). (A functionally equivalent Rust firmware also exists -
see the [Rust guide](./development-guide-rust.md).)

## Firmware

### Source layout

| File | Responsibility |
| ---- | --- |
| `teensy_6502_bridge.ino`  | Entry point: `setup()`/`loop()` and the main request-response loop (`loop_prod`); selects the firmware mode at compile time |
| `configuration.h` | User configuration: the `PINS_MAP` pin assignment, debug/diagnostics mode switches, debug clock speed |
| `src/pins.{hpp,cpp}` | GPIO layer: pin-id mapping, reading/writing individual pins, (de)serializing all 40 pins to/from the 5-byte payload |
| `src/cpu.{hpp,cpp}` | CPU control: pin directions, the reset sequence, and per-cycle data-bus direction handling (drive gated on `RW && PHI2`) |
| `src/io.{hpp,cpp}` | Serial I/O: non-blocking message assembly (`try_read_msg`) and error replies (`send_error`) |
| `src/protocol.{hpp,cpp}`  | Message framing: types, sizes, checksums, buffer conversions - pure logic, no hardware access |
| `src/debug.{hpp,cpp}` | Standalone debug mode (see below) |
| `src/diagnostics.{hpp,cpp}` | On-board diagnostics mode |
| `src/hardware.hpp` | Includes the real Arduino/Teensy headers, or the test mocks when `RUNNING_TESTS` is defined |

A useful rule of thumb: `protocol.cpp` knows nothing about hardware, `pins.cpp`/`cpu.cpp` know
nothing about messages, and `io.cpp` plus the `.ino` glue the two worlds together.

### Building and flashing

```bash
make build     # compile with arduino-cli into ./target
make upload    # flash with teensy-loader-cli
```

Prerequisites and alternatives (Arduino IDE, Nix shell) are described in the
[main README](../README.md). On macOS `make upload` doesn't work - see the
[macOS guide](./macos.md) for the working alternatives.

### Firmware modes

The mode is selected at compile time in `configuration.h` (or via compiler flags):

- **Production** (default) - the serial-controlled bridge loop described in the
  [protocol specification](./protocol.md).
- **Debug** (`#define DEBUG_TEENSY_BRIDGE`) - the bridge clocks the CPU by itself
  (one half-cycle every `CYCLE_DURATION` milliseconds) and prints the address/data/status pins to
  the serial port. No host application is needed - this mode is handy for verifying your wiring
  with nothing but a serial monitor.
- **Diagnostics** (`#define ENABLE_DIAGNOSTICS`) - on-board diagnostics firmware.

Note: the Teensy Arduino core ignores defines injected from the command line, so all of these
switches must be edited in `configuration.h` before running `make build`.

### Optional ILI9341 display

`#define ENABLE_DISPLAY` in `configuration.h` turns the PCB's LCD header into a live front panel
(`src/display.{hpp,cpp}`). It requires the Adafruit display libraries:

```bash
arduino-cli lib install "Adafruit ILI9341" "Adafruit GFX Library" "Adafruit BusIO"
```

The wiring matches PCB v1 and needs no configuration: the screen sits on SPI1 (MOSI=26, SCK=27),
D/C on pin 10, with CS tied to ground and RST pulled high on the board. The panel shows:

- a header with the current address/data (hex), a read/write indicator, and per-signal
  "asserted" chips (active-low signals light up when low);
- a sweeping 8-lane logic analyzer (PHI2, SYNC, RW, VP, ML, IRQ, NMI, RES) with one column per
  half-cycle, fed from the same 5-byte payload the serial protocol uses;
- a footer with the last opcode fetch (`SYNC` address + opcode), a cycle counter (reset by `RES`)
  and the measured effective clock rate (`HOLD` when the host pauses, e.g. in `--step` mode).

The front panel in action

Refreshing is rate-limited (`DISPLAY_REFRESH_MS`) and draws only changed regions (in free-run the
expensive text readouts update just once per second, since they are a blur at speed anyway), but it
still costs roughly 15% of free-run throughput; while stepping or idle it costs nothing. The firmware is
harmless with no screen attached, and before a host connects it shows a splash screen (with a cat).

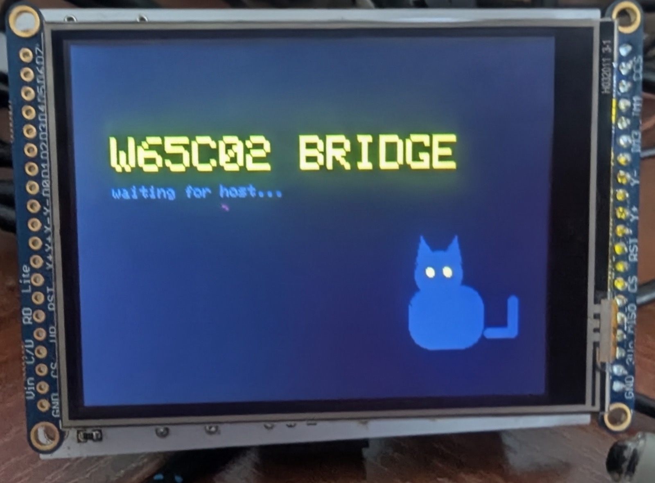
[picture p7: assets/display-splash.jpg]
Splash screen


### Tests

The firmware logic is covered by host-side unit and integration tests - no hardware required:

```bash
make test
```

This compiles everything in `tests/` together with the `src/` modules, with `RUNNING_TESTS`
defined so that `src/hardware.hpp` pulls in the mocks from `tests/mocks/` instead of the Arduino
headers. The mocked `Serial` supports scripted input (`_set_read_buff`), `peek`/`available`, and
captures everything written to it (`_get_out_buff`), so both directions of the protocol can be
asserted on.

To add tests: create a `tests/test_<area>.cpp` file (the Makefile picks up `tests/*.cpp`
automatically), give it an `<area>_tests_all()` entry function, and register that function in
`tests/tests.hpp` and `tests/tests.cpp`.

## Host runner (examples/cpp)

The C++ runner executes a 6502 binary on the real CPU while emulating 64 kB of RAM on the host.

### Source layout

| File | Responsibility |
| ---- | --- |
| `main.cpp` | CLI parsing, serial-port configuration (raw 8N1, DTR/RTS), wiring everything together |
| `runner.{cpp,hpp}`  | The clock loop: reset sequence, half-cycle stepping, memory reads/writes, logging, BRK detection |
| `pins.{cpp,hpp}` | `W65C02Pins` - a decoded view of the 40 pins, convertible to/from the 5-byte payload |
| `pin_utils.{cpp,hpp}` | Low-level helpers for picking single pins and address/data fields out of a payload |
| `memory.{cpp,hpp}`  | 64 kB RAM emulation and program loading |
| `configuration.hpp` | Knobs: program/interrupt addresses, per-half-cycle delay, BRK/max-cycles stop conditions |

### Building and running

```bash
make build-cpp-example
PORT=/dev/ttyACM0 make run-cpp
# or manually:
./examples/cpp/example.out --port /dev/ttyACM0 --program examples/test.p [--halfcycles] [--step]
```

`--step` pauses after every logged cycle with the CPU frozen (the W65C02 is fully static, so it
simply holds its state) and waits for a command on stdin: `Enter` advances one step, a number runs
that many steps, `c` switches back to free-running, `q` quits.

### Configuration knobs (`configuration.hpp`)

- `PROGRAM_ADDR` / `INTERRUPT_ADDR` - where the binary is loaded and where the IRQ/NMI vectors point.
- `CYCLE_DURATION` - extra delay per half-cycle in microseconds. `0` (the default) runs at full
  speed; the bridge's response is the synchronization point, so no delay is needed for correctness.
  Increase it to watch execution in slow motion (e.g. to observe board LEDs).
- `EXIT_ON_BRK` - stop when the CPU fetches a `BRK` opcode.
- `MAX_CYCLES` - hard stop after N cycles (`0` = no limit).

### Writing test programs

Any 6502 assembler producing a plain binary works. The examples use [ACME](https://github.com/meonwax/acme)
(available in the project's Nix shell):

```bash
acme -f plain -o program.p --cpu w65c02 program.asm
```

The runner loads the binary at `PROGRAM_ADDR` (`$0200` by default) and seeds the reset vector to
point at it, so the program needs no header. Ending with `BRK` makes the runner stop cleanly -
see [examples/test.asm](../examples/test.asm) for a complete, commented example.

## Formatting

The repository uses [treefmt](https://github.com/numtide/treefmt) (with astyle for C++) - run
`treefmt` before committing.

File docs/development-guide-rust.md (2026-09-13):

# Rust development guide

This guide covers the two Rust parts of the project: the bare-metal bridge firmware in
[firmware-rust](../firmware-rust/) and the host runner in [examples/rust](../examples/rust/).
For the wire format they share, see the [protocol specification](./protocol.md).

## Firmware (firmware-rust)

An alternative to the C++ firmware in the repository root, functionally equivalent on the wire:
the same message framing, checksum validation, error replies and data-bus gating (the bus is
driven only during the high clock phase of read cycles). The host runners and test programs work
with either firmware unchanged. Built on [teensy4-rs](https://github.com/mciantyre/teensy4-rs)
(`teensy4-bsp` + `imxrt-usbd` + `usbd-serial`), plain stable Rust - no Arduino toolchain involved.

The Rust firmware currently has no debug/diagnostics modes and no ILI9341 display support - when
you need those, flash the C++ firmware. To tell them apart, the Rust firmware enumerates as
`W65C02 Bridge (Rust)`.

### Source layout

| File | Responsibility |
| ---- | --- |
| `src/main.rs` | Board and GPIO setup, USB CDC plumbing, and the request-response loop |
| `src/protocol.rs` | Message framing: sizes, checksums, error replies, the byte-stream accumulator (host-tested) |
| `src/payload.rs` | The 40-bit pin payload bit layout (host-tested, incl. a real hardware-captured vector) |
| `src/lib.rs` | The hardware-independent logic: `no_std` on the target, `std` for host tests |
| `Makefile` | `build` / `hex` / `flash` / `test` targets |
| `.cargo/config.toml` | Default target (`thumbv7em-none-eabihf`) and the linker script |

### Building, flashing, testing

```bash
cd firmware-rust
make build   # cargo build --release (rustup installs the target on first run)
make hex     # ELF -> teensy-6502-bridge.hex via the toolchain's llvm-objcopy
make flash   # flash with teensy-loader-cli
make test    # host-side unit tests of the protocol/payload logic
```

`make flash` expects a native `teensy-loader-cli` on the PATH (on macOS build it from source -
see the [macOS guide](./macos.md); the nixpkgs build does not work there).

Reflashing needs no button press: the running Rust firmware reboots into the HalfKay bootloader
when the serial port is opened at **134 baud** - the same convention Teensyduino uses:

```bash
/bin/stty -f /dev/cu.usbmodemXXXX 134   # macOS (full path in case GNU coreutils shadows stty)
stty -F /dev/ttyACM0 134                # Linux
```

### Design notes

- **Bare metal with a polling loop, not async.** The protocol is a latency-bound
  request-response exchange over a single peripheral - exactly the shape where a poll loop is
  the right architecture, not a compromise. (`embassy-imxrt` targets the i.MX RT600 family, not
  the Teensy's RT1062; RTIC would be the natural framework if interrupt-driven structure is ever
  needed.)
- **Type-checked pin mapping.** Every GPIO is created through the HAL's typed pad API
  (`teensy4-pins`), so a wrong pin/port pairing fails at build or boot time instead of silently
  writing to the wrong register - the failure mode that killed the first attempt at this
  firmware.
- **SION on all output pads.** The Software Input On bit keeps a driven pad's input path alive,
  so output levels can be read back through PSR. `sample()` and the `RW && PHI2` data-bus gate
  depend on it - without SION, PHI2 always reads low, the data bus is never driven and the CPU
  executes garbage from a floating bus.
- **Data-bus direction flips** use the HAL's documented-reentrant `Output::without_pin` /
  `Input::without_pin` constructors - a single GDIR register write per line.

The [firmware README](../firmware-rust/README.md) repeats the practical parts of this section
next to the code.

## Host runner (examples/rust)

A workstation-side program that executes a 6502 binary on the real CPU while emulating 64 kB of
RAM on the host. The Rust and C++ runners are functionally identical, so pick whichever
toolchain you prefer.

### Source layout

| File | Responsibility |
| ---- | --- |
| `src/main.rs` | CLI parsing (clap), memory initialization and vector seeding, serial-port opening (DTR/RTS asserted) |
| `src/runner.rs` | The clock loop: reset sequence, half-cycle stepping, memory reads/writes, logging, BRK detection, error-reply handling |
| `src/pins.rs` | The `Pins` struct - a decoded view of the 40 CPU pins, convertible to/from the 5-byte payload |
| `src/protocol.rs` | Generic `Message<SIZE>` framing with checksum computation and validation; `PinsMsg = Message<5>` |
| `src/configuration.rs` | Knobs: per-half-cycle delay, raw-message logging |

### Building and running

```bash
cd examples/rust
cargo build
cargo run -- --port /dev/ttyACM0 --program ../test.p [--halfcycles]

# or from the repository root:
PORT=/dev/ttyACM0 make run-rust
```

On macOS the port is named `/dev/cu.usbmodem*` - see the [macOS guide](./macos.md).

CLI flags:

- `--port` / `-p` - the serial device.
- `--program` / `-f` - path to a plain 6502 binary; it is loaded at `$0200` and the reset, IRQ and
  NMI vectors are seeded automatically.
- `--halfcycles` - log both halves of every clock cycle and include the `PHI1O`/`PHI2O` pins.
- `--step` - step mode: pause after every logged cycle (or half-cycle, with `--halfcycles`) with the
  CPU frozen, and wait for a command on stdin: `Enter` advances one step, a number runs that many
  steps, `c` switches back to free-running, `q` quits. As the W65C02 is fully static, the CPU simply
  holds its state while paused - handy for inspecting board LEDs or probing signals.

### Configuration knobs (`src/configuration.rs`)

- `CYCLE_DURATION` - extra delay per half-cycle. `Duration::ZERO` (the default) runs at full speed;
  the bridge's response is the synchronization point, so no delay is needed for correctness.
  Increase it to watch execution in slow motion (e.g. to observe board LEDs).
- `SHOW_RAW_DATA` - print every raw message (type, payload bytes, checksum) as it is sent and
  received; useful when debugging the protocol itself.

### How the runner works

1. `reset()` holds the CPU's `RES/` pin low for two full cycles (four half-cycle messages), then
   releases it.
2. `step()` executes one half-cycle: it toggles `PHI2` in the payload, sends a pins message and
   reads the response. During the low phase it captures the address and the `RW/` state; during the
   high phase it either supplies data from the emulated memory (reads) or stores the data pins into
   it (writes).
3. The loop stops when the CPU fetches a `BRK` opcode (`SYNC` high with data `$00`).

The runner reads the type byte of every response first: a pins message (type 2) is 7 bytes, while an
error reply from the bridge (type 0) is only 3 bytes and makes the runner panic with the reported
error code. Checksums of all pins responses are validated.

### Tests

```bash
cd examples/rust
cargo test
```

The tests cover the payload/`Pins` conversions and the message framing - pure logic, no hardware or
serial port required.

### Writing test programs

Any 6502 assembler producing a plain binary works. The examples use [ACME](https://github.com/meonwax/acme)
(available in the project's Nix shell):

```bash
acme -f plain -o program.p --cpu w65c02 program.asm
```

End the program with `BRK` so the runner stops cleanly - see
[examples/test.asm](../examples/test.asm) for a complete, commented example.

### Writing your own client

`runner.rs` is intentionally small - if you want to build something else on top of the bridge
(a debugger UI, an emulator comparator, a whole emulated machine), the pieces to reuse are
`protocol.rs` and `pins.rs`, plus the half-cycle algorithm from the
[protocol specification](./protocol.md). Everything the bridge can do is reachable through that
one message type.

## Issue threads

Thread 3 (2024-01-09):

Add support for W65C816 CPU

ddrcode, 2024-01-09:
As the W65C02 and W65C816 have very similar pinouts, it wold be beneficial to make the project support both CPUs. The major difference here is that pin 35, that is currently (W65C02) unconnected (as NC), plays an important role in case of W65C816 (emulation mode).

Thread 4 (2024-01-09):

Serial port data - move from little-endian to big-endian

ddrcode, 2024-01-09:
Moving to big-endian notation makes more sense. In such case the entire CPU status can be represented as a single 64-bit number, where bit 40 is equivalent of pin 40, etc. In the current, little-endian notation, the order is a little bit convoluted: the first byte of a buffer represents pins 1-8, etc, that eventually makes (some) sense it form of a byte-array, but not in case of a number representation.

ddrcode, 2024-01-09:
Implemented as part of #9

Closed 2024-01-09.

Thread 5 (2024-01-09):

Support the bi-directional nature of the READY pin

ddrcode, 2024-01-09:
At this stage the READY pin (pin no 2) is considered as an input - it can be only controlled externally, but actually it is bi-directional. The CPU can turn the signal low in response to `WAI` opcode (_wait-for-interrupt_) and then reset it to high when an interrupt occurs. There are two options to support the bi-directionality:

#### Solution 1
The bridge software can watch for the `WAI` opcode and in case of it's occurance it may change the pin direction from input to output.

#### Solution 2
The bridge could simulate the behavior of W65C02S Hard Core model, where READY state is represented by three pins: `RDY` (input), `WAITN` (output), `WAITP` (output). The `WAITN` signal goue low and `WAITP` goes high when `WAI` instruction is executed. Thit solution gives more control over the READY state, but requires introduction of additional, "virtual", pins.

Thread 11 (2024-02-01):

Improve the communication protocol

ddrcode, 2024-02-01:
## Problem

Currently "the protocol" for data exchange between computer and Teensy (and vice versa) just sends all pins state (as 40-bit buffer) and nothing else. Although the simplicity is good, with such approach there is no option of handling errors. Some minimal protocol would be required. That may be particularly important when the #2 will be implemented.

## Proposal

Every message consist of at least one byte (the message type), optionally followed by some data and (optionally again) a checksum. Examples:

- `{0}{code}` - error with error code
- `{1}` - tick the CPU clock
- `{2}{data}{checksum}` - sends all pins data (5 bytes) with a checksum (1 byte with overflow)
- `{3}` - reset the CPU

Note: the message type is a number (uint8), not an ASCII digit.

### Error codes
- 1: unrecognised command
- 2: incorrect checksum

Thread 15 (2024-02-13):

PCB issues

ddrcode, 2024-02-13:
Here is a collective list of problems reported after first trying of the PCB (v1.0).

Issues
- CPU labels are too close to the pins - hence one character is not visible
- BE LED should be lit for inverted signal
- TBC - it looks like the reset component should be DS1818-20, rather than DS1818-10

Improvements
- horizontal reset button

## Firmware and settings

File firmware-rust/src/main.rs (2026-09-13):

//! W65C02-Teensy 4.1 bridge firmware (Rust edition).
//!
//! A bare-metal implementation of the same serial protocol as the C++
//! firmware (see `docs/protocol.md`): 7-byte framed messages over USB CDC,
//! one request-response pair per clock half-cycle, with checksum validation,
//! error replies, and the data bus driven only during the high clock phase
//! of read cycles.
//!
//! Extra: opening the serial port at 134 baud reboots the board into the
//! HalfKay bootloader (same convention as Teensyduino), so reflashing
//! doesn't require pressing the button.

#![no_std]
#![no_main]

use teensy4_panic as _;

use teensy4_bsp as bsp;

use bsp::board;
use bsp::hal::gpio::{Input, Output, Port};
use bsp::hal::iomuxc;
use bsp::pins::t41::Pins;
use bsp::usbd::{BusAdapter, EndpointMemory, EndpointState};

use static_cell::StaticCell;
use usb_device::bus::UsbBusAllocator;
use usb_device::device::{StringDescriptors, UsbDeviceState};
use usb_device::prelude::*;
use usb_device::UsbError;
use usbd_serial::SerialPort;

use bridge::payload::{self, bits, BUFF_SIZE};
use bridge::protocol::{
    checksum, error_msg, Accumulator, Event, ERR_INVALID_CHECKSUM, ERR_INVALID_MSG_TYPE, MSG_PINS,
    PINS_MSG_SIZE,
};

static EP_MEMORY: EndpointMemory<2048> = EndpointMemory::new();
static EP_STATE: EndpointState<8> = EndpointState::new();
static USB_ALLOC: StaticCell<UsbBusAllocator<BusAdapter>> = StaticCell::new();

type Device<'a> = UsbDevice<'a, BusAdapter>;
type Serial<'a> = SerialPort<'a, BusAdapter>;

//--------------------------------------------------------------------------
// GPIO layer

/// Creates an output GPIO, panicking on a pin/port mismatch (a build-time
/// mapping bug - the panic handler blinks the LED).
///
/// SION keeps the pad's input path alive so the driven level can be read
/// back through PSR - `sample()` and the PHI2 gate in `handle_cycle()`
/// depend on it. (`alternate()` preserves the bit, so setting it before
/// `Port::output` is safe.)
fn out<P, const N: u8>(port: &mut Port, mut pin: P) -> Output
where
    P: iomuxc::gpio::Pin<N>,
{
    iomuxc::set_sion(&mut pin);
    match port.output(pin) {
        Ok(output) => output,
        Err(_) => panic!(),
    }
}

/// Creates an input GPIO, panicking on a pin/port mismatch.
fn inp<P, const N: u8>(port: &mut Port, pin: P) -> Input
where
    P: iomuxc::gpio::Pin<N>,
{
    match port.input(pin) {
        Ok(input) => input,
        Err(_) => panic!(),
    }
}

/// One data bus line. Holds two aliased handles: a DR writer (used only
/// while the bus is driven) and a PSR reader (valid in both directions).
/// The actual direction is flipped via [`CpuPins::set_data_direction`].
struct DataPin {
    port_no: u8,
    offset: u32,
    writer: Output,
    sample: Input,
}

fn data_pin<P, const N: u8>(port: &mut Port, pin: P) -> DataPin
where
    P: iomuxc::gpio::Pin<N>,
{
    let offset = P::OFFSET;
    // `out` muxes the pad (with SION, so the bus can be sampled even while
    // driven) and briefly sets GDIR to out...
    let writer = out(port, pin);
    // ...and this reverts GDIR so the bus starts released (input).
    let sample = Input::without_pin(port, offset);
    DataPin {
        port_no: N,
        offset,
        writer,
        sample,
    }
}

/// All CPU-facing GPIOs, following the default `PINS_MAP` of the C++
/// firmware (see the pinout table in the README).
struct CpuPins {
    gpio1: Port,
    gpio2: Port,
    gpio3: Port,
    gpio4: Port,

    // Teensy outputs (CPU inputs)
    ready: Output,
    irq: Output,
    nmi: Output,
    be: Output,
    so: Output,
    reset: Output,
    phi2: Output,

    // Teensy inputs (CPU outputs)
    vp: Input,
    phi1o: Input,
    ml: Input,
    sync: Input,
    rw: Input,
    phi2o: Input,
    addr: [Input; 16],

    data: [DataPin; 8],
    data_out: bool,
}

impl CpuPins {
    fn new(
        mut gpio1: Port,
        mut gpio2: Port,
        mut gpio3: Port,
        mut gpio4: Port,
        pins: Pins,
    ) -> Self {
        let g1 = &mut gpio1;
        let g2 = &mut gpio2;
        let g3 = &mut gpio3;
        let g4 = &mut gpio4;

        // The "M" net (pin 18) is routed to CPU pin 35 through the PCB's
        // configuration switch - unused with a W65C02 (switch open), so drive
        // it low to keep the net and its LED buffer input defined. With a
        // W65C816 it will carry the E (emulation) status output.
        out(g1, pins.p18).clear();

        let cpu = Self {
            ready: out(g1, pins.p21),
            irq: out(g4, pins.p3),
            nmi: out(g4, pins.p5),
            be: out(g1, pins.p19),
            so: out(g1, pins.p20),
            reset: out(g1, pins.p23),
            phi2: out(g2, pins.p13),

            vp: inp(g1, pins.p0),
            phi1o: inp(g4, pins.p2),
            ml: inp(g4, pins.p4),
            sync: inp(g2, pins.p6),
            rw: inp(g1, pins.p17),
            phi2o: inp(g1, pins.p22),

            // A0..A15
            addr: [
                inp(g2, pins.p7),
                inp(g2, pins.p8),
                inp(g2, pins.p9),
                inp(g2, pins.p11),
                inp(g2, pins.p12),
                inp(g1, pins.p24),
                inp(g1, pins.p25),
                inp(g3, pins.p28),
                inp(g4, pins.p29),
                inp(g3, pins.p30),
                inp(g3, pins.p31),
                inp(g2, pins.p32),
                inp(g4, pins.p33),
                inp(g2, pins.p34),
                inp(g2, pins.p35),
                inp(g2, pins.p36),
            ],

            // D0..D7
            data: [
                data_pin(g1, pins.p16),
                data_pin(g1, pins.p15),
                data_pin(g1, pins.p14),
                data_pin(g1, pins.p41),
                data_pin(g1, pins.p40),
                data_pin(g1, pins.p39),
                data_pin(g1, pins.p38),
                data_pin(g2, pins.p37),
            ],
            data_out: false,

            gpio1,
            gpio2,
            gpio3,
            gpio4,
        };

        // Safe defaults: all active-low control signals deasserted
        cpu.ready.set();
        cpu.irq.set();
        cpu.nmi.set();
        cpu.be.set();
        cpu.so.set();
        cpu
    }

    /// Holds the CPU in reset for a while, then releases it (the host
    /// performs its own protocol-level reset sequence afterwards).
    fn reset_cpu(&mut self) {
        self.reset.clear();
        delay_ms(100);
        delay_ms(100);
        self.reset.set();
        delay_ms(100);
    }

    fn port(&mut self, no: u8) -> &mut Port {
        match no {
            1 => &mut self.gpio1,
            2 => &mut self.gpio2,
            3 => &mut self.gpio3,
            _ => &mut self.gpio4,
        }
    }

    /// Drives or releases the data bus (GDIR flip on all 8 lines).
    fn set_data_direction(&mut self, drive: bool) {
        if drive == self.data_out {
            return;
        }
        self.data_out = drive;
        for i in 0..8 {
            let (no, offset) = (self.data[i].port_no, self.data[i].offset);
            let port = self.port(no);
            if drive {
                let _ = Output::without_pin(port, offset);
            } else {
                let _ = Input::without_pin(port, offset);
            }
        }
    }

    /// Applies the host-controlled pins from an incoming payload.
    /// Mirrors the C++ `set_pins_state`.
    fn apply(&mut self, p: &[u8; BUFF_SIZE]) {
        set_level(&self.irq, payload::get_bit(p, bits::IRQ));
        set_level(&self.nmi, payload::get_bit(p, bits::NMI));
        set_level(&self.be, payload::get_bit(p, bits::BE));
        set_level(&self.phi2, payload::get_bit(p, bits::PHI2));
        set_level(&self.so, payload::get_bit(p, bits::SO));
        set_level(&self.reset, payload::get_bit(p, bits::RES));

        if self.rw.is_set() {
            // latch data values; they appear on the bus once driven
            for i in 0..8 {
                set_level(&self.data[i].writer, payload::get_bit(p, payload::data_bit(i as u8)));
            }
        }
    }

    /// Drives the data bus only during the high clock phase of read cycles
    /// (like a memory's output enable gated with RW and PHI2). Mirrors the
    /// C++ `handle_cycle`.
    fn handle_cycle(&mut self) {
        let drive = self.rw.is_set() && self.phi2.is_pad_high();
        self.set_data_direction(drive);
    }

    /// Samples all 40 CPU pins into a payload. Mirrors the C++
    /// `get_pins_state` (VDD/VSS/NC bits stay zero).
    fn sample(&self) -> [u8; BUFF_SIZE] {
        let mut p = [0u8; BUFF_SIZE];
        payload::set_bit(&mut p, bits::VP, self.vp.is_set());
        payload::set_bit(&mut p, bits::RDY, self.ready.is_pad_high());
        payload::set_bit(&mut p, bits::PHI1O, self.phi1o.is_set());
        payload::set_bit(&mut p, bits::IRQ, self.irq.is_pad_high());
        payload::set_bit(&mut p, bits::ML, self.ml.is_set());
        payload::set_bit(&mut p, bits::NMI, self.nmi.is_pad_high());
        payload::set_bit(&mut p, bits::SYNC, self.sync.is_set());
        for i in 0..16 {
            payload::set_bit(&mut p, payload::addr_bit(i), self.addr[i as usize].is_set());
        }
        for i in 0..8 {
            payload::set_bit(&mut p, payload::data_bit(i), self.data[i as usize].sample.is_set());
        }
        payload::set_bit(&mut p, bits::RW, self.rw.is_set());
        payload::set_bit(&mut p, bits::BE, self.be.is_pad_high());
        payload::set_bit(&mut p, bits::PHI2, self.phi2.is_pad_high());
        payload::set_bit(&mut p, bits::SO, self.so.is_pad_high());
        payload::set_bit(&mut p, bits::PHI2O, self.phi2o.is_set());
        payload::set_bit(&mut p, bits::RES, self.reset.is_pad_high());
        p
    }
}

#[inline]
fn set_level(pin: &Output, high: bool) {
    if high {
        pin.set();
    } else {
        pin.clear();
    }
}

fn delay_ms(ms: u32) {
    cortex_m::asm::delay(ms * (board::ARM_FREQUENCY / 1_000));
}

//--------------------------------------------------------------------------
// USB plumbing

/// Writes a complete message and flushes it to the host, pumping the USB
/// device as needed (the equivalent of the C++ `Serial.send_now()`).
fn send_msg(device: &mut Device, serial: &mut Serial, bytes: &[u8]) {
    let mut written = 0;
    while written < bytes.len() {
        match serial.write(&bytes[written..]) {
            Ok(n) => written += n,
            Err(UsbError::WouldBlock) => {
                device.poll(&mut [serial]);
            }
            Err(_) => return,
        }
    }
    loop {
        match serial.flush() {
            Err(UsbError::WouldBlock) => {
                device.poll(&mut [serial]);
            }
            _ => break,
        }
    }
}

/// Reboots into the HalfKay bootloader (the Teensyduino convention).
fn reboot_to_bootloader() -> ! {
    cortex_m::interrupt::disable();
    unsafe { core::arch::asm!("bkpt #251") };
    loop {
        cortex_m::asm::nop();
    }
}

//--------------------------------------------------------------------------
// Entry point

#[bsp::rt::entry]
fn main() -> ! {
    let board::Resources {
        gpio1,
        gpio2,
        gpio3,
        gpio4,
        pins,
        usb,
        ..
    } = board::t41(board::instances());

    let mut cpu = CpuPins::new(gpio1, gpio2, gpio3, gpio4, pins);
    cpu.reset_cpu();

    let bus = BusAdapter::new(usb, &EP_MEMORY, &EP_STATE); // high-speed by default
    bus.set_interrupts(false); // polling mode
    let alloc = USB_ALLOC.init(UsbBusAllocator::new(bus));
    let mut serial = SerialPort::new(alloc);
    let mut device = UsbDeviceBuilder::new(alloc, UsbVidPid(0x16C0, 0x0483))
        .device_class(usbd_serial::USB_CLASS_CDC)
        .max_packet_size_0(64)
        .unwrap()
        .strings(&[StringDescriptors::default()
            .manufacturer("ddrcode")
            .product("W65C02 Bridge (Rust)")
            .serial_number("6502-RS-2")])
        .unwrap()
        .build();

    let mut configured = false;
    let mut acc = Accumulator::new();

    loop {
        device.poll(&mut [&mut serial]);

        if device.state() != UsbDeviceState::Configured {
            configured = false;
            acc.clear();
            continue;
        }
        if !configured {
            // finalize endpoint configuration (imxrt-usbd requirement)
            device.bus().configure();
            configured = true;
        }

        if serial.line_coding().data_rate() == 134 {
            reboot_to_bootloader();
        }

        if !serial.dtr() {
            acc.clear();
            continue;
        }

        let mut buf = [0u8; 64];
        let count = match serial.read(&mut buf) {
            Ok(n) => n,
            Err(_) => 0,
        };

        for &byte in &buf[..count] {
            match acc.push(byte) {
                Event::Pending => {}
                Event::UnknownType => {
                    send_msg(&mut device, &mut serial, &error_msg(ERR_INVALID_MSG_TYPE));
                }
                Event::Complete {
                    msg_type,
                    payload,
                    checksum_ok,
                } => {
                    if msg_type != MSG_PINS {
                        send_msg(&mut device, &mut serial, &error_msg(ERR_INVALID_MSG_TYPE));
                    } else if !checksum_ok {
                        send_msg(&mut device, &mut serial, &error_msg(ERR_INVALID_CHECKSUM));
                    } else {
                        cpu.apply(&payload);
                        cpu.handle_cycle();
                        let sampled = cpu.sample();
                        let mut reply = [0u8; PINS_MSG_SIZE];
                        reply[0] = MSG_PINS;
                        reply[1..6].copy_from_slice(&sampled);
                        reply[6] = checksum(&reply[..6]);
                        send_msg(&mut device, &mut serial, &reply);
                    }
                }
            }
        }
    }
}

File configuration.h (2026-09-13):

// CONFIGURATION
// Edit this file to adjust the config of Teensy Bridge.

// Uncomment the line below if you want to test the project
// without any client app, serial monitor (like Arduino
// Serial Monitor or screen).
// This is handy in case of testing the correctness of your wiring.

// #define DEBUG_TEENSY_BRIDGE

// Uncomment to build bridge with on-board diagnostics firmware instead of
// serial-controlled bridge loop.
// #define ENABLE_DIAGNOSTICS

// the clock (in ms) is required only for debug mode.
// The bridge itself is being "clocked" by the COM port
// messages and as such doesn't provide any notion of cycles.
#define CYCLE_DURATION 500

// Uncomment to enable the optional ILI9341 status display connected to the
// PCB's LCD header (SPI1: MOSI=26, SCK=27, MISO=1, D/C=10; CS grounded and
// RST pulled high on the board). Shows a live logic analyzer of the CPU
// signals, address/data readouts and the effective clock rate.
// Requires libraries: Adafruit ILI9341, Adafruit GFX Library, Adafruit BusIO
//   arduino-cli lib install "Adafruit ILI9341" "Adafruit GFX Library" "Adafruit BusIO"
// Note: refreshing the screen costs some throughput in free-run mode
// (roughly 15%); it has no cost while the CPU is stepped or idle.
#define ENABLE_DISPLAY

// Teensy pin of the "M" net: routed to CPU pin 35 through the PCB's
// configuration switch (S2). Unused with a W65C02 (keep the switch open, per
// WDC the NC pin must stay unconnected) - the firmware drives the net low so
// it and its LED buffer input don't float. With a W65C816 it will carry the
// E (emulation) status output - see issue #3.
#define M_PIN 18

#define DISPLAY_PIN_DC 10
#define DISPLAY_PIN_CS -1   // tied to GND on the PCB
#define DISPLAY_PIN_RST -1  // pulled high on the PCB
#define DISPLAY_ROTATION 1  // 1 or 3, depending on the screen orientation
#define DISPLAY_REFRESH_MS 100

// PIN CONFIGURATION
// For each W65C02 PIN (as in the comments), provide Teensy 4.1 pin no.
// Pins 8, 21 and 35 are not data pins, so they can be ignored.
// Pins 2, 4, 6, 36 can be skipped if connected directly to power
// (resistors should be used).
// Value 255 means "ignore".
// In case of W65C816 set pin 35 to 18
#define PINS_MAP\
   0,  /*     VP <-- |  1      40 | <-- RES   */     23, \
  21,  /*    RDY <-> |  2      39 | --> PHI2O */     22, \
   2,  /*  PHI1O <-- |  3      38 | <-- SO    */     20, \
   3,  /*    IRQ --> |  4      37 | <-- PHI2  */     13, \
   4,  /*     ML <-- |  5     @36 | <-- BE    */     19, \
   5,  /*    NMI --> |  6      35 | --- NC    */    255, \
   6,  /*   SYNC <-- |  7     *34 | --> RW    */     17, \
 255,  /*    VDD --> |  8     *33 | <-> D0    */     16, \
   7,  /*     A0 <-- |  9*    *32 | <-> D1    */     15, \
   8,  /*     A1 <-- | 10*    *31 | <-> D2    */     14, \
   9,  /*     A2 <-- | 11*    *30 | <-> D3    */     41, \
  11,  /*     A3 <-- | 12*    *29 | <-> D4    */     40, \
  12,  /*     A4 <-- | 13*    *28 | <-> D5    */     39, \
  24,  /*     A5 <-- | 14*    *27 | <-> D6    */     38, \
  25,  /*     A6 <-- | 15*    *26 | <-> D7    */     37, \
  28,  /*     A7 <-- | 16*    *25 | --> A15   */     36, \
  29,  /*     A8 <-- | 17*    *24 | --> A14   */     35, \
  30,  /*     A9 <-- | 18*    *23 | --> A13   */     34, \
  31,  /*    A10 <-- | 19*    *22 | --> A12   */     33, \
  32,  /*    A11 <-- | 20*     21 | --> GND   */    255

constexpr bool SERIAL_ENABLED = true;
constexpr bool ETHERNET_ENABLED = false;

#define THROW_ERROR_IF_NOT_FAST

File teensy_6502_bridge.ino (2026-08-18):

/*
   This code makes Teensy 4.1 a bridge betwen serial port and 65C02 processor.

   Created with Teensyduino
   Author: ddrcode
   Repository: https://github.com/ddrcode/teensy_6502_bridge/

   Compilation: make build
   Upload to Teensy: make upload

   The MIT License
   Copyright (C) 2023-2024 ddrcode

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
   THE SOFTWARE IS PROVIDED “AS IS”, WITHOUT WARRANTY OF ANY KIND, EXPRESS
   OR IMPLIED, INCLUDING BUT NOT LIMITED TO THE WARRANTIES OF MERCHANTABILITY,
   FITNESS FOR A PARTICULAR PURPOSE AND NONINFRINGEMENT. IN NO EVENT SHALL
   THE AUTHORS OR COPYRIGHT HOLDERS BE LIABLE FOR ANY CLAIM, DAMAGES OR OTHER
   LIABILITY, WHETHER IN AN ACTION OF CONTRACT, TORT OR OTHERWISE, ARISING
   FROM, OUT OF OR IN CONNECTION WITH THE SOFTWARE OR THE USE OR OTHER
   DEALINGS IN THE SOFTWARE.
*/

#include "src/hardware.hpp"
#include "configuration.h"
#include "src/protocol.hpp"
#include "src/pins.hpp"
#include "src/cpu.hpp"
#include "src/io.hpp"

#ifdef DEBUG_TEENSY_BRIDGE
    #include "src/debug.hpp"
#endif

#ifdef ENABLE_DIAGNOSTICS
    #include "src/diagnostics.hpp"
#endif

#ifdef ENABLE_DISPLAY
    #include "src/display.hpp"
#endif

uint8_t pin_ids[40];
pins_t pins = setup_pins(pin_ids);
uint8_t buff[7];

void setup()
{
    Serial.begin(8388608); // value ignored on Teensy for USB connection
    setup_cpu(pins);
    reset(pins);
#ifdef ENABLE_DISPLAY
    display_setup();
#endif
}

void loop()
{
    // do nothing until serial connected
    if (!Serial.dtr()) {
#ifdef ENABLE_DISPLAY
        display_idle();
#endif
        return;
    }

#if defined(ENABLE_DIAGNOSTICS)
    loop_diagnostics(pins);
#elif defined(DEBUG_TEENSY_BRIDGE)
    loop_debug(pins);
#else
    loop_prod();
#endif

#ifdef ENABLE_DISPLAY
    display_refresh();
#endif
}

void loop_prod()
{
    message_t msg;
    if (!try_read_msg(&msg)) return;

    if (msg.type != MSG_PINS) {
        send_error(ERR_INVALID_MSG_TYPE);
        return;
    }

    if (!validate_checksum(&msg)) {
        send_error(ERR_INVALID_CHECKSUM);
        return;
    }

    set_pins_state(pin_ids, pins, msg.data);
    handle_cycle(pins);
    get_pins_state(pin_ids, msg.data);
    msg.checksum = compute_checksum(&msg);
    msg_to_buff(&msg, buff);
    Serial.write(buff, 7);
    Serial.send_now();

#ifdef ENABLE_DISPLAY
    display_capture(msg.data);
#endif
}

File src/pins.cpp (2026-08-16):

/*
   Pins handling API

   Created with Teensyduino
   Author: ddrcode
   Repository: https://github.com/ddrcode/teensy_6502_bridge/

   The MIT License
   Copyright (C) 2023-2024 ddrcode

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
   THE SOFTWARE IS PROVIDED “AS IS”, WITHOUT WARRANTY OF ANY KIND, EXPRESS
   OR IMPLIED, INCLUDING BUT NOT LIMITED TO THE WARRANTIES OF MERCHANTABILITY,
   FITNESS FOR A PARTICULAR PURPOSE AND NONINFRINGEMENT. IN NO EVENT SHALL
   THE AUTHORS OR COPYRIGHT HOLDERS BE LIABLE FOR ANY CLAIM, DAMAGES OR OTHER
   LIABILITY, WHETHER IN AN ACTION OF CONTRACT, TORT OR OTHERWISE, ARISING
   FROM, OUT OF OR IN CONNECTION WITH THE SOFTWARE OR THE USE OR OTHER
   DEALINGS IN THE SOFTWARE.
*/

#include <cstdint>

#include "hardware.hpp"
#include "../configuration.h"
#include "pins.hpp"

void set_pin_mode(uint8_t pin_id, int mode)
{
    if (pin_id != 255) {
        pinMode(pin_id, mode);
    }
}

void set_data_pins_mode(uint8_t data[8], int direction)
{
    for (int i = 0; i < 8; ++i) {
        pinMode(data[i], direction);
    }
}

uint16_t get_val_from_pins(uint8_t addr_pins[], int len)
{
    int addr = 0;
    for (int i = 0; i < len; ++i) {
        addr |= read_pin(addr_pins[i]) == HIGH ? (1 << i) : 0;
    }
    return addr;
}

uint8_t read_data_bus(pins_t& pins)
{
    uint8_t value = 0;
    for (int i = 0; i < 8; ++i) {
        value |= read_pin(pins.data[i]) == HIGH ? (1 << i) : 0;
    }
    return value;
}

void write_data_bus(pins_t& pins, const uint8_t value)
{
    for (int i = 0; i < 8; ++i) {
        digitalWriteFast(pins.data[i], (value & (1 << i)) ? HIGH : LOW);
    }
}

void get_pins_state(uint8_t pin_ids[], uint8_t buff[BUFFSIZE])
{
    for(int i=0; i<BUFFSIZE; ++i) {
        buff[BUFFSIZE - i - 1] = 0;
        for(int j=0; j < 8; ++j) {
            auto id = pin_ids[i*8 + j];
            if (id != 255) { // 255 = not connected; 0 is a valid Teensy pin (VP)
                buff[BUFFSIZE - i - 1] |= read_pin(id) == HIGH ? 1 << j : 0;
            }
        }
    }
}

void set_pins_state(uint8_t pin_ids[], pins_t& pins, const uint8_t buff[BUFFSIZE])
{
    write_pin(pin_ids, 3,  buff); // irq
    write_pin(pin_ids, 5,  buff); // nmi
    write_pin(pin_ids, 35, buff); // be
    write_pin(pin_ids, 36, buff); // phi2
    write_pin(pin_ids, 37, buff); // so
    write_pin(pin_ids, 39, buff); // reset

    if (read_pin(pins.rw) == HIGH) {
        for (int i = 32; i > 24; --i) {
            write_pin(pin_ids, i, buff);
        }
    }
}

int read_pin(const uint8_t pin_id)
{
    return pin_id == 255 ? LOW : digitalReadFast(pin_id);
}

void write_pin(const uint8_t pin_id, const int val)
{
    if (pin_id != 255) {
        digitalWriteFast(pin_id, val);
    }
}

void write_pin(uint8_t pin_ids[], const uint8_t pin_id, const uint8_t buff[BUFFSIZE])
{
    uint8_t id = pin_ids[pin_id];
    if (id != 255) {
        bool val = buff[(39-pin_id) / 8] & (1 << (pin_id % 8));
        digitalWriteFast(id, val ? HIGH : LOW);
    }
}

void set_pin_ids(uint8_t ids[])
{
    uint8_t x[40] = { PINS_MAP };
    for (int i = 0; i < 40; i += 2) {
        ids[i / 2] = x[i];
        ids[39 - i / 2] = x[i + 1];
    }
}

pins_t setup_pins(uint8_t pin_ids[])
{
    set_pin_ids(pin_ids);
    uint8_t *p = pin_ids;

    pins_t pins = {
        .ready = p[1],
        .ml = p[4],
        .be = p[35],
        .so = p[37],
        .reset = p[39],
        .phi1o = p[2],
        .phi2 = p[36],
        .phi2o = p[38],
        .irq = p[3],
        .nmi = p[5],
        .rw = p[33],
        .addr = { p[8], p[9], p[10], p[11], p[12], p[13], p[14], p[15], p[16], p[17], p[18], p[19], p[21], p[22], p[23], p[24] },
        .data = { p[32], p[31], p[30], p[29], p[28], p[27], p[26], p[25] },
        .sync = p[6],
        .vp = p[0]
    };
    return pins;
}

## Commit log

2024-02-01 PCB v1 - schematics and design (#10)
    * PCB - initial push
    * Update README.md
    * PCB configuration pins
    * digitalRead/Write replaced with fast version (Teensy-specific)
    * MVP PCB
    * schematics and renders
    * explanation of the contents added to README
    * configuration adjustment
    [Drill_NPTH_Through.DRL, Drill_PTH_Through.DRL, Drill_PTH_Through_Via.DRL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]
2024-02-01 Link to schematic and detailed description on wiring (#12)
2026-01-08 Improved protocol (#17)
    * msg to buff
    * code split (not compiling)
    * fixed compilation issues but untested
    * working version with protocol
    * tests
    * integration tests
    * adjusted to work on linux
    * First working version since 2 years (#16)
    * fixed example
    * rust working example
    * diagnostics added
    * output from examples and cleanup
    * pcb photo
    [configuration.h]
2026-08-16 Cleanup (#18)
    * .envrc removed
    * docs improved
    * error handling
    * sleep reduced to 0 by default
    * handle_cycle to be guarded by phi2 (not only rw)
    * development guide
    * test_io.cpp added
    * maual stepping
    [io.cpp]
2026-08-18 screen support - splash and logic analyzer (#20)
    [configuration.h]
2026-09-13 working rust firmware (#21)
    [configuration.h]
2026-09-13 updates regarding NC/M pin
    [configuration.h]
